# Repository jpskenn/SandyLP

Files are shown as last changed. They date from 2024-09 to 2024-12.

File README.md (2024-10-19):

# SandyLP（サンディ エルピー）

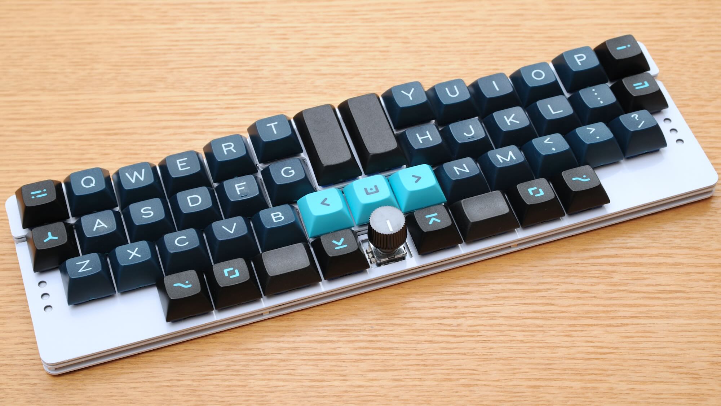
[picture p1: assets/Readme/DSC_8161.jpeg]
  

SandyLP is a 40% keyboard with symmetrical row staggered layout and key height optimization.

Layered PCB will make height differences for each key.
This covers the lack of optimization to physical key layout in two dimensions that only adjust x-y plane.

---

SandyLPは、スイッチの配置を立体的にして高さ方向への最適化を加えた、左右対称ロースタッガード配列の40%キーボードです。  

平面上のキーレイアウトだけでは最適化しきれない部分を、キーの位置に応じてスイッチを配置する高さを変えることで補っています。

前機種の[Sandy](https://github.com/jpskenn/Sandy)を元に、ロープロファイルスイッチへの対応と、レイアウトの調整をおこなっています。

名前の由来は、立体的、つまり3Dという意味を込めたSandyに、ロープロファイル版（＝ Low Profile version）を意味するLPを追加しました。

## 特徴

### 左右対称のキーレイアウト  

[Jones](https://github.com/jpskenn/Jones)と同様の、2行目と3行目にずれのない、左右対称なシンメトリカル ロースタッガードのレイアウトです。  
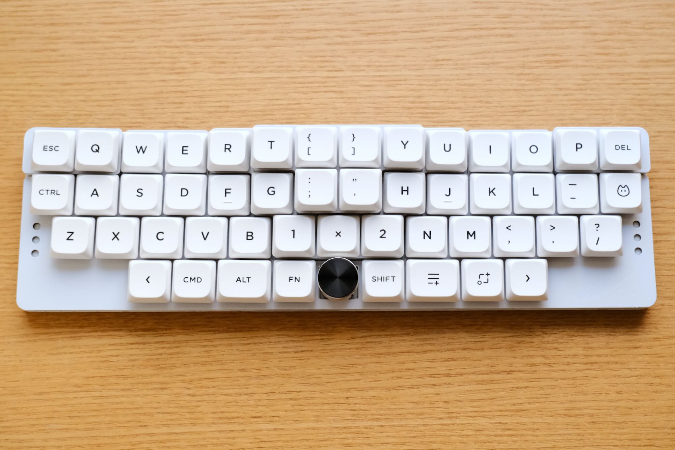
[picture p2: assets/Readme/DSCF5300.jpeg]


一般的なロースタッガードなレイアウトとの共通性を残しつつ、左右対称で打鍵しやすくなるよう、[SemiErgo Layout](https://github.com/mtei/SemiErgo_Layout)に準ずるキーマッピングで使用することを念頭に設計しています。  
Z行の左右端にシフトキーを用意していないので、スペースキーを「Space and Shift」として使うと便利です。

`T`と`Y`、`G`と`H`の間の2キーは実際のところそれほど使用することはありませんが、ここに2キー分の間隔があいてることで左右の手を広げることになり、肩を疲れにくくします。  
また、この間隔がゼロになると左右の親指が当たって動きを妨げてしまうため、あえて間隔をあけています。

このレイアウトは、市販の各種キーキャップセットのうち「Base Kit」と呼ばれる基本的なキットですべてを埋めることができます。また、104キーの英語キーキャップセットでも十分実用が可能です。
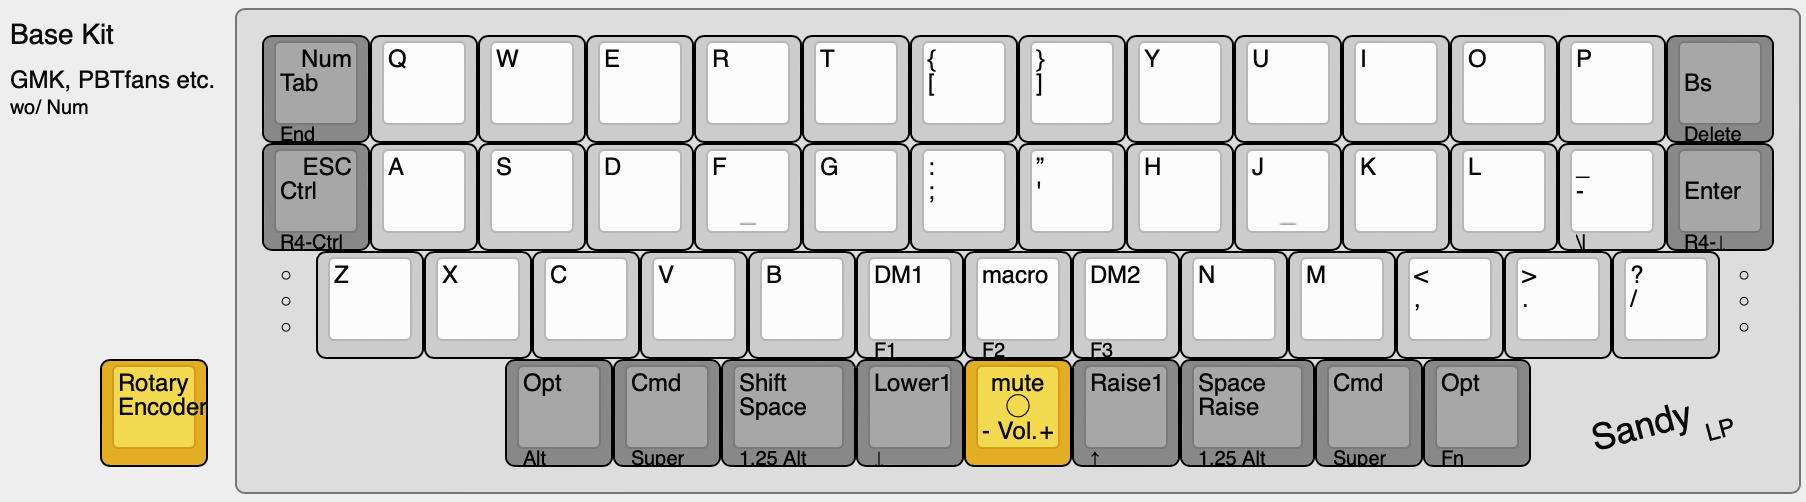
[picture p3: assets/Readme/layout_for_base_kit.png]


詳しくは、[Keyboard Layout Editor: SandyLP](https://www.keyboard-layout-editor.com/#/gists/29f5da09ffa69ab85efa4c68b556282b)を参照してください。

### キースイッチを立体的に配置  

前機種の[Sandy](https://github.com/jpskenn/Sandy)と同じく、キースイッチを3段階の高さで立体的に配置しています。  
平面上ではキーを配置できる範囲が限られるため、一部のキーはどうしても指が届きにくくなってしまいます。例えば、[Jones](https://github.com/jpskenn/Jones)では左右対称のレイアウトを採用することで右手小指の`P`や`Back Space`、`Enter`などは打鍵しやすくなりましたが、右手人差し指の`Y`は少し遠く感じられました。  
このような箇所について、キーの配置を高くすることで打鍵しやすさを向上させています。  

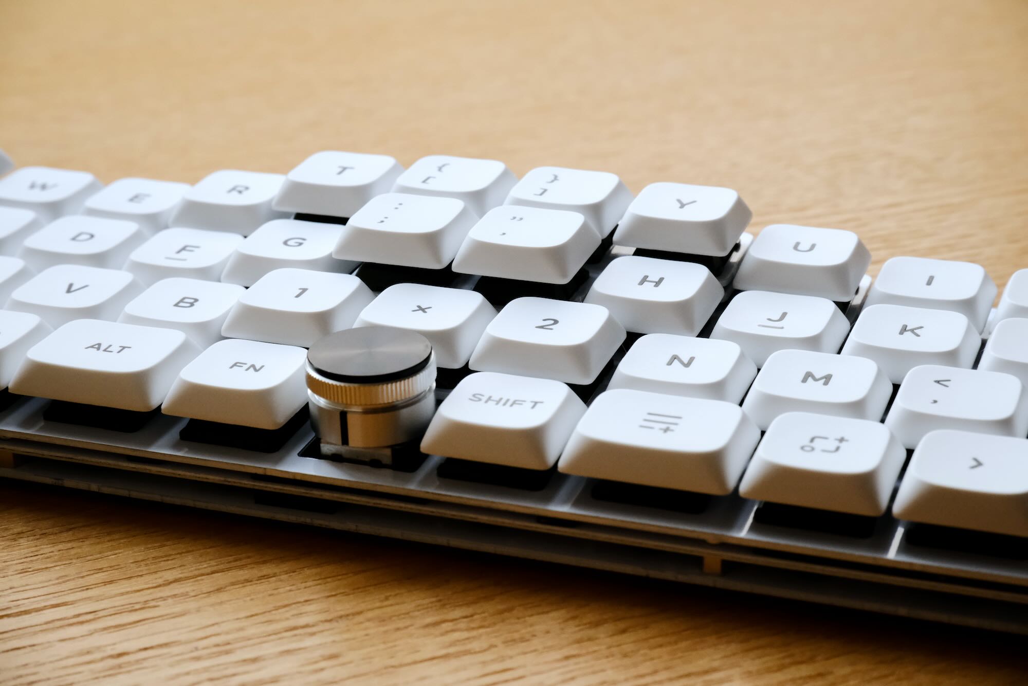
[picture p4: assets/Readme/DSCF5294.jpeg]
キースイッチの高さ（中央部分）

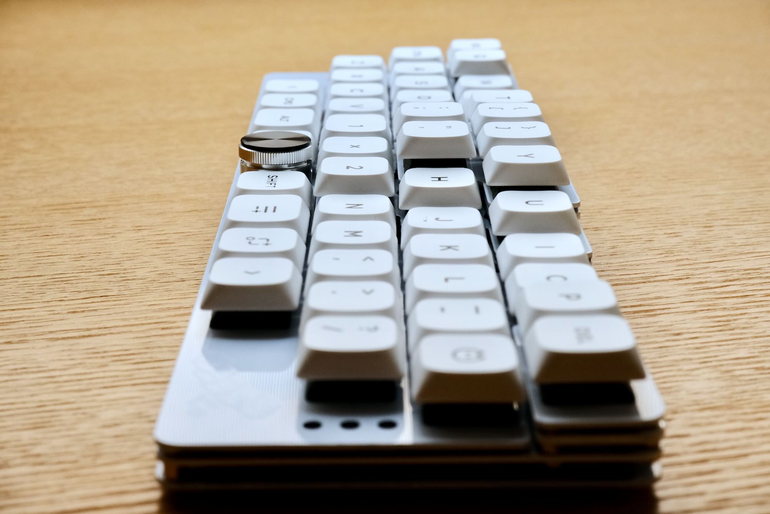
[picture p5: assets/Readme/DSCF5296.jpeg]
キースイッチの高さ（横から）


キーの高さはLow（基準高＝0mm）, Middle（3.6mm）, High（8.7mm）の3段階で、以下のように配置されます。  
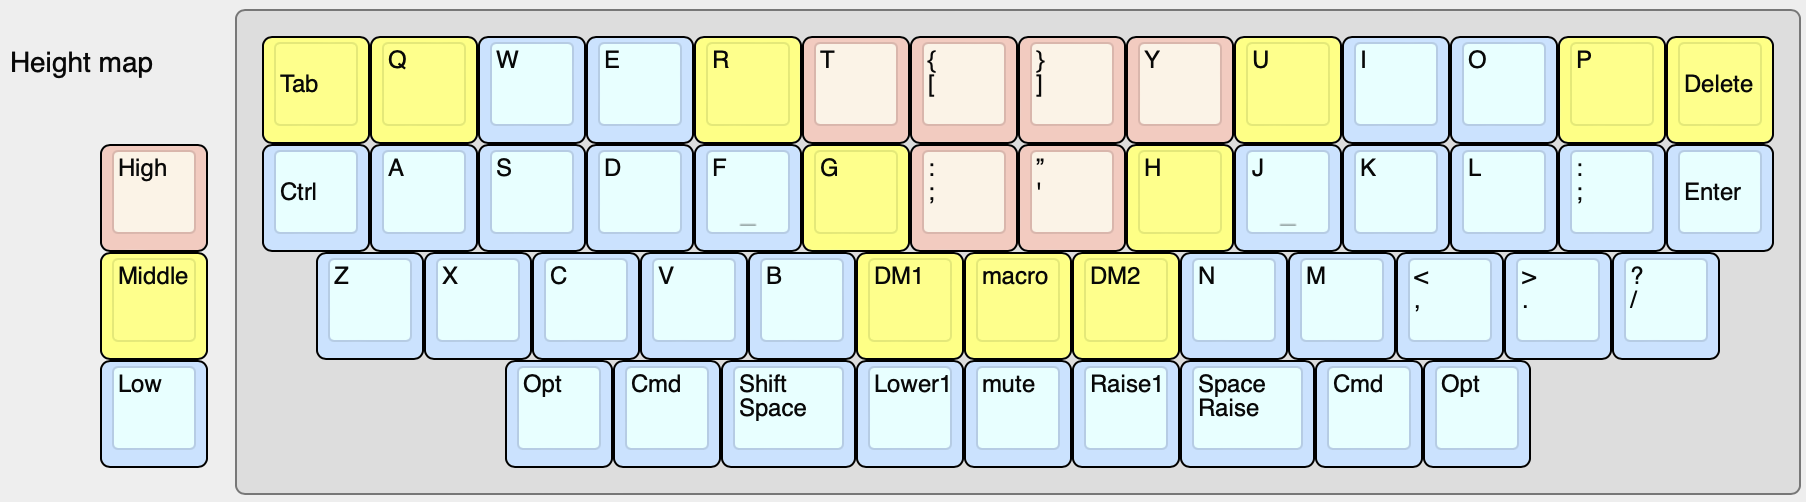
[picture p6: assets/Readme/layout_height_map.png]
キーの高さ


### キーボード自体が低い（薄い）  

ロープロファイルの`Choc V2`スイッチを採用することでキーボード自体が低くなりました。  
前機種のSandyからは7.2mm（※1）低くなり、パームレストを使わずとも、手首をあまり反らさないポジションで打鍵できます。

※1 ボトムプレートから1段目のスイッチ軸の天面までの高さを比較。なお、Sandyは理論上あと0.8mm低くすることが可能です。

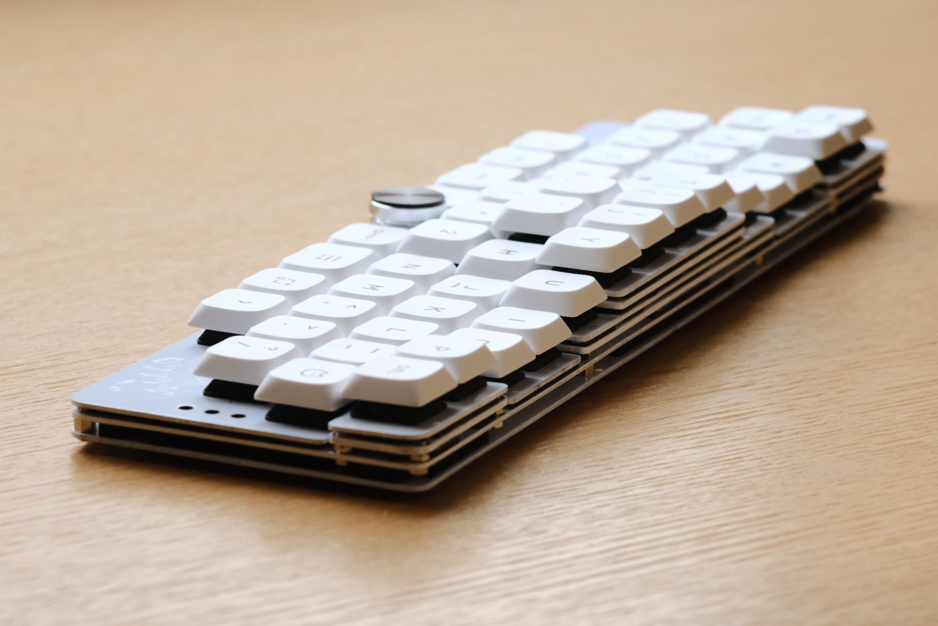
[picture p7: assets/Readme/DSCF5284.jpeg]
キースイッチの高さ


### RP2040を採用した構成により、多機能なファームウェアを使用可能

RP2040を採用した構成により、キーボード向けのファームウェアを格納するには十分すぎるほどのフラッシュ容量を得ることができました。  
エンコーダーやオーディオ、その他各種機能の同時有効化や、多数のレイヤーを使用するなど、多機能なファームウェアを使用可能です。

### Remap、Vialによるキー割り当ての変更  

初期書き込み済みのファームウェアは[Remap](https://remap-keys.app/)に対応しており、プログラミング等の知識がなくても、キーマッピングやロータリーエンコーダへの割り当てを、ブラウザ等を使って簡単に変更できます。  

また、Vial対応のファームウェアに書き換えて使用することもできます。

### オプション機能  

- ロータリーエンコーダ
- インジケータLED
- オーディオ

## ビルドガイド

- [SandyLP（DN0010）](/docs/BuildGuide_DN0010.md)（最新版）

## SNSタグ

[#SandyLP_kbd](https://twitter.com/search?q=%23SandyLP_kbd)

## ギャラリー

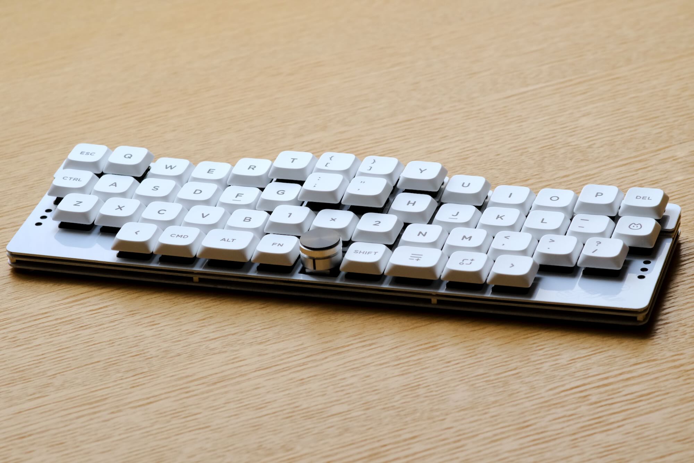
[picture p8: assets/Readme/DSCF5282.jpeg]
  
w/ NuPhy nSA BOW

SandyLP keyboard  
w/ Signature Plastics DSS Solarized Dark

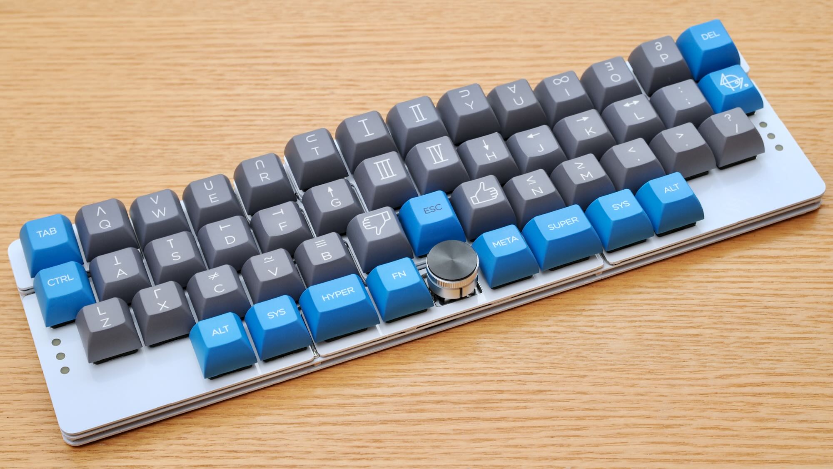
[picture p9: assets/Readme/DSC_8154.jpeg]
  
w/ Keyreative KAT Space Cadet, DN0011 Switch Plate

## 参考事例

- [TreK Lagoon](https://zenn.dev/digitarhythm/articles/a559b4b19fc959) by おおやけハジメ さん
- [Sparrow62](https://github.com/74th/sparrow62-buildguide/blob/master/sparrow62_v2.md) by 74th さん

## 開発経緯

以前開発した[Sandy](https://github.com/jpskenn/Sandy)を1年半ほど使い続け、日常使いの長期ロードテストとして十分な情報を得ることができました。  
その情報を元にSandyのアップデート版（Sandy DN0040）の開発をおこない、あとは基板製造の発注をするだけの段階となっていましたが、Sandyの課題のひとつとして挙げていた手首の負荷軽減、つまりキーボードを低くする変更を取り込まなかったことが様々な思いの中でほんのりと燻り続けていました。

ちょうどその頃、Choc V2スイッチのラインナップにたいへん素性の良い静音タイプが追加されました。そして、自分が普段好んで使っているMX用のキーキャップをそのスイッチと組み合わせて使えそうだという情報が得られたことから、ロープロファイルのスイッチを使用したSandyの派生版開発に踏み切りました。  

使用するスイッチの変更で、派生版の開発においてそこそこの量の設計変更が見込まれることから、ついでにキーレイアウトも変更することにしました。  
これまでに開発した`Jones`や`Sandy`では、頒布・販売することを念頭に想定するユーザーの最大公約数的なところへ歩み寄ったレイアウトにしていましたが、今回は自分の使用スタイルを最優先し、自分にとって不要な数字行や左右端のシフトキーなどを取り除いて、少し尖ったレイアウトに変更しました。

こうして、SandyLPが誕生することとなりました。

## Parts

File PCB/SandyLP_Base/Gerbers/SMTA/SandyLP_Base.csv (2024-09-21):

Reference | Value | Datasheet | Footprint | Qty | DNP | LCSC | LCSC-Reserve
C1,C2 | 10u | ~ | Capacitor_SMD:C_1206_3216Metric | 2 |  | C77090
C3,C4,C5,C6,C7,C8,C9,C10,C11,C12,C14,C15,C18,C19,C20,C21 | 100n | ~ | Capacitor_SMD:C_0402_1005Metric | 16 |  | C1525
C13,C16,C17 | 2.2uF | ~ | Capacitor_SMD:C_0402_1005Metric | 3 |  | C307418
D1,D2,D3,D4,D5,D6,D7,D8,D9,D10,D11,D12,D13,D14,D15,D16,D17,D18,D19,D20,D21,D22,D23,D24,D25,D26,D27,D28,D29,D30,D31,D32,D33,D34,D35 | D | ~ | locallib:D_SOD-123_Emphasized_Direction_Line_Reference_on_bottom | 35 |  | C81598
D99 | PRTR5V0U2X | https://assets.nexperia.com/documents/data-sheet/PRTR5V0U2X.pdf | Package_TO_SOT_SMD:SOT-143 | 1 |  | C78442
F1 | Fuse | ~ | Fuse:Fuse_0603_1608Metric | 1 |  | C187605
H_btm_1,H_btm_2,H_btm_3,H_btm_4,H_btm_5,H_btm_6,H_btm_7,H_btm_8,H_btm_9,H_btm_10,H_btm_11,H_mid_1,H_mid_2,H_mid_3,H_mid_4,H_mid_5,H_mid_6,H_mid_7,H_mid_8,H_mid_9,H_mid_10,H_mid_11,H_mid_12,H_mid_13,H_mid_14,H_mid_15,H_mid_16,H_mid_17,H_mid_18 | MountingHole | ~ | -- ミックスされた値 -- | 29
J1 | Conn_01x10_Pin | ~ | Connector_PinHeader_1.00mm:PinHeader_1x10_P1.00mm_Vertical | 1
J7 | USB_C_Receptacle_USB2.0 | https://www.usb.org/sites/default/files/documents/usb_type-c.zip | locallib:USB_C_Receptacle_HRO_TYPE-C-31-M-12 | 1 |  | C165948
J8 | Conn_01x03 | ~ | locallib:PinHeader_1x03_P2.54mm_Vertical_All_circle | 1
L1,L2,L3,L4,L5,L6 | SK6812MINI-E |  | locallib:YS-SK6812MINI-E_middle_hole_with_small_pad | 6
LOGO1 | Logo_Base | ~ | locallib:SandyLP_logo_w60 | 1
LS1,LS2 | Speaker | ~ | Buzzer_Beeper:Buzzer_Murata_PKMCS0909E | 2 |  |  | C910763
Q1 | BSS138 | https://www.onsemi.com/pub/Collateral/BSS138-D.PDF | Package_TO_SOT_SMD:SOT-23 | 1 |  | C78284
R1,R2 | 5.1k | ~ | Resistor_SMD:R_0402_1005Metric | 2 |  | C25905
R5,R8,R10,R11,R12,R13,R14 | 1k | ~ | Resistor_SMD:R_0402_1005Metric | 7 |  | C11702
R6,R7 | 27 | ~ | Resistor_SMD:R_0402_1005Metric | 2 |  | C25100
R9 | 10k | ~ | Resistor_SMD:R_0402_1005Metric | 1 |  | C25744
SD1 | Schottky diode | ~ | Diode_SMD:D_SOD-123 | 1 |  | C8598
STLED1 | LED_GREEN | ~ | LED_SMD:LED_0402_1005Metric | 1 |  | C130723
SW1 | BOOT | ~ | Button_Switch_SMD:SW_SPST_TL3342 | 1 |  |  | C2886897
SW2 | RESET | ~ | Button_Switch_SMD:SW_SPST_TL3342 | 1 |  |  | C2886897
SW_/1,SW_;1,SW_<1,SW_>1,SW_A1,SW_B1,SW_C1,SW_CTL1,SW_D1,SW_E1,SW_ENT1,SW_F1,SW_I1,SW_J1,SW_K1,SW_L1,SW_LALTu1,SW_LSPC1,SW_LWIN1,SW_M1,SW_N1,SW_O1,SW_R5CNT_L1,SW_R5CNT_R1,SW_RALT1,SW_RSPC1,SW_RWIN1,SW_S1,SW_V1,SW_W1,SW_X1,SW_Z1 | SW_Push | ~ | locallib:Kailh_socket_ChocV2 | 32
SW_R5CNT_C1 | RotaryEncoder_Switch | ~ | locallib:ChocV2_AND_RotaryEncoder_Alps_EC11K-Switch_Vertical_H20mm_NPTH_MP_minimal | 1
T_C0,T_C1,T_C2,T_C3,T_C4,T_C5,T_C6,T_R0,T_R1,T_R2,T_R3,T_R4,T_R5,T_R6,T_R7 | Conn_01x01 | ~ | locallib:TestPoint_THTPad_D2.0mm_Drill1.0mm | 15
U1 | NCP1117-3.3_SOT223 | http://www.onsemi.com/pub_link/Collateral/NCP1117-D.PDF | Package_TO_SOT_SMD:SOT-223-3_TabPin2 | 1 |  | C347222
U2 | RP2040 | https://datasheets.raspberrypi.com/rp2040/rp2040-datasheet.pdf | locallib:RP2040-QFN-56 | 1 |  | C2040
U3 | W25Q128JVPIQ | http://www.winbond.com/resource-files/w25q128jv_dtr%20revc%2003272018%20plus.pdf | Package_SON:WSON-8-1EP_6x5mm_P1.27mm_EP3.4x4.3mm | 1 |  | C190862
Y1 | 12MHz | ~ | Crystal:Resonator_SMD_Murata_CSTxExxV-3Pin_3.0x1.1mm | 1 |  | C341520

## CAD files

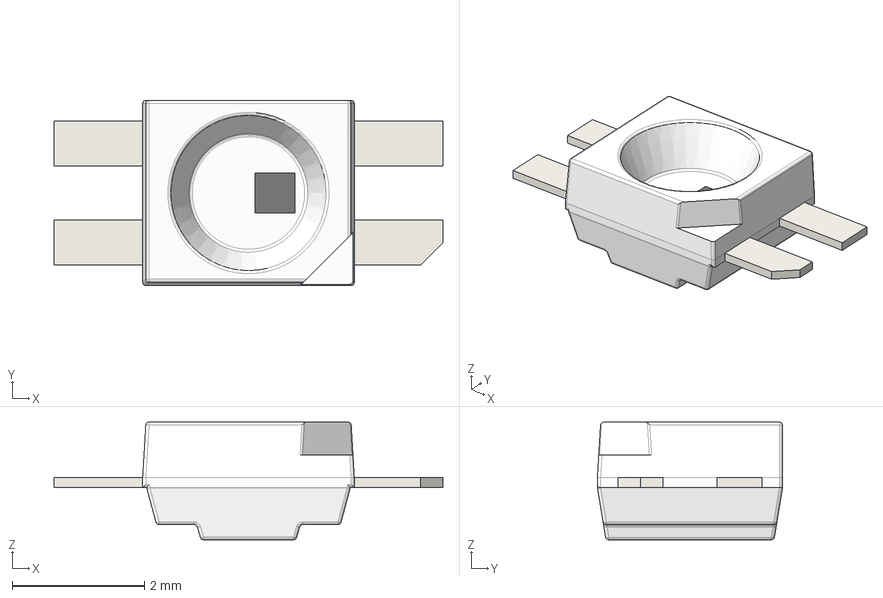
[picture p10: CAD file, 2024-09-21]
PCB/SandyLP_Base/lib_LED/LED_SK6812MINI-E.step
5.88 x 2.80 x 1.78 mm

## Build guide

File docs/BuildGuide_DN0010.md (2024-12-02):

# SandyLP（DN0010）ビルドガイド

このドキュメントは、SandyLP（DN0010）を組み立てるためのビルドガイドです。

開発番号の`DN0010`は、各基板のうら側に記載されています。  
（Mid左右用スイッチプレートには記載がありません。）
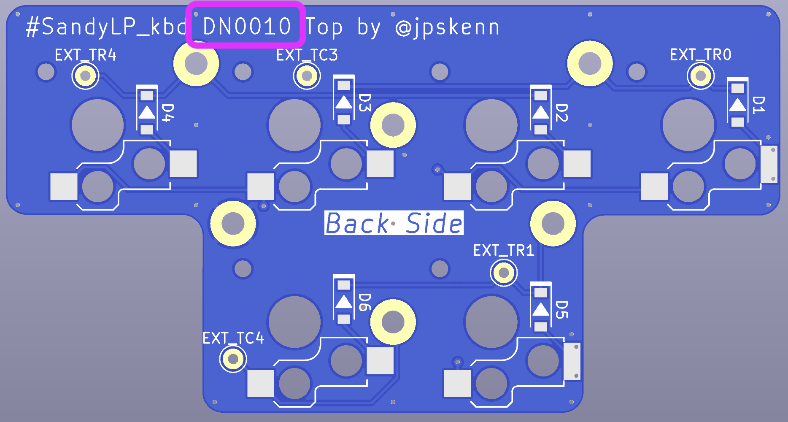
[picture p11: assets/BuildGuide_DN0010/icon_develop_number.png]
開発ナンバー


SandyLPのコンセプトや特徴、ビルド例などについては、こちらの[README](/README.md)をご覧ください。

ビルドガイド全体に目を通して作業手順を把握しておくとミスの防止につながりますので、ぜひ、一度お読みになってから組み立て作業を始めてください。

## 目次

<!-- @import "[TOC]" {cmd="toc" depthFrom=1 depthTo=3 orderedList=false} -->

<!-- code_chunk_output -->

- [SandyLP（DN0010）ビルドガイド](#sandylpdn0010ビルドガイド)
  - [目次](#目次)
  - [注意事項](#注意事項)
  - [部品リスト](#部品リスト)
    - [キット内容](#キット内容)
    - [別途用意が必要な部品](#別途用意が必要な部品)
    - [オプション部品](#オプション部品)
  - [組み立てに使用する工具](#組み立てに使用する工具)
  - [組み立て手順](#組み立て手順)
    - [組み立て前の確認](#組み立て前の確認)
    - [【こだわり作業】基板とスイッチプレート側面をマジックで塗る](#こだわり作業基板とスイッチプレート側面をマジックで塗る)
    - [部品のはんだ付け](#部品のはんだ付け)
    - [基板へのネジ止めとゴムシート貼り](#基板へのネジ止めとゴムシート貼り)
    - [スイッチプレートへのゴムシート貼り](#スイッチプレートへのゴムシート貼り)
    - [基板とスイッチプレートをひとつに組み合わせて、スイッチを取り付ける](#基板とスイッチプレートをひとつに組み合わせて-スイッチを取り付ける)
    - [動作確認する](#動作確認する)
    - [ボトムプレートを取り付ける](#ボトムプレートを取り付ける)
    - [キーキャップを取り付ける](#キーキャップを取り付ける)
  - [ユーザーズマニュアル・カスタマイズガイド](#ユーザーズマニュアルカスタマイズガイド)
    - [初期ファームウェアの機能と設定値](#初期ファームウェアの機能と設定値)
    - [SandyLP関連ファイル](#sandylp関連ファイル)
    - [ファームウェアを書き換える](#ファームウェアを書き換える)
    - [EEPROMを消去して初期状態に戻す](#eepromを消去して初期状態に戻す)
    - [電源LEDを点灯しないようにする](#電源ledを点灯しないようにする)
    - [キーキャップの選び方](#キーキャップの選び方)
  - [サービスマニュアル](#サービスマニュアル)
    - [パーツリスト](#パーツリスト)
    - [基板セットアップ](#基板セットアップ)

<!-- /code_chunk_output -->

## 注意事項

開発ナンバー`DN0010`と`DN0011`はSandyLPの試作版であり、組み立てやすくする工夫や細部の調整が施されていません。

半田付けするのが難しい箇所があったりするため、自作キーボードや電子工作についてある程度わかっている方や、多少のことは自分でなんとかできる方以外は手を出さないようにしてください。

## 部品リスト

このキットを組み立てて完成させるためには、[キット内容](#キット内容)に加え、[別途用意が必要な部品](#別途用意が必要な部品)が必要です。  

[オプション部品](#オプション部品)は用意しなくてもかまいません。使いたい機能に応じて用意してください。  

### キット内容

このキットに同梱されている部品等の内容です。  

| 部品名 | 個数 | 備考 |
| :-- | :--: | :-- |
| ご案内リーフレット | 1 | |
| 基板Base | 1 | この基板のみ、多数の部品を取り付け済み。 |
| 基板Mid中央 | 1 | |
| 基板Mid左右 | 2 | 同一形状の2枚のうち、ひとつをおもて側、もうひとつをうら側にして使用。 |
| 基板Top | 1 ||
| Base用スイッチプレート | 1 | 両面使えるリバーシブル仕様。好みのデザインの面をおもて側にして使用。 |
| Mid中央用スイッチプレート | 1 ||
| Mid左右用スイッチプレート | 2 | 同一形状の2枚のうち、ひとつをおもて側、もうひとつをうら側にして使用。 |
| Top用スイッチプレート | 1 | |
| ボトムプレート | 1 ||
| 短いスペーサー<br>両メネジ M2 3mm | 11 | [ヒロスギ ASB-2003E](https://hirosugi.co.jp/products/B/ASB-E.html#bx3) |
| 長いスペーサー<br>両メネジ M2 3.5mm | 6 |  [ヒロスギ ASB-2003.5E](https://hirosugi.co.jp/products/B/ASB-E.html#bx3) |
| ナット<br>M2 2種 高さ1.6mm | 35 | 予備1個含む。[ウィルコ FNT-02N-2](https://wilco.jp/products/F/FNT-N-2.html) |
| ワッシャー<br>M2 内径2.3mm 外径4.3mm 厚さ0.4mm| 19 | 予備1個含む。[ウィルコ FW-0204-04N](https://wilco.jp/products/F/FW-N.html#page3) |
| 短いネジ（2mm）<br>M2 2mm | 11 | [十字穴付なべ小ねじ](https://jp.misumi-ec.com/vona2/detail/110302280810/?ProductCode=BKJ2-2) |
| 短いネジ（3mm）<br>M2 3mm | 22 | 予備1個含む。[ウィルコ F-0230N-02](https://wilco.jp/products/F/F-N-02.html#page3) |
| 長いねじネジ<br>M2 6mm | 19 | 予備1個含む。[ウィルコ F-0260N-02](https://wilco.jp/products/F/F-N-02.html#page3) |
| ゴム足（大） | 2 | [光 HIKARI KKU-190](https://www.yodobashi.com/product/100000001001980663/) |
| ゴム足（小） | 5 | [CS-102](https://www.3mcompany.jp/3M/ja_JP/p/d/v000453068/) |
| ダイオード<br>1N4148W SOD123 | 20 | 予備3個含む。<br>[高速スイッチング・ダイオード 1N4148W](https://akizukidenshi.com/catalog/g/g107084/) |
| LED<br>SK6812MINI-E | 6 | [マイコン内蔵ＲＧＢＬＥＤ　ＳＫ６８１２ＭＩＮＩ－Ｅ](https://akizukidenshi.com/catalog/g/gI-15478/) |
| Chocスイッチ用ソケット | 50 | 最下行中央にロータリーエンコーダを取り付けない場合は49個。<br>[Kailh Switch Socket（Kailh Choc ロープロファイル用）](https://shop.yushakobo.jp/products/a01ps?variant=37665172553889) |
| 太くて薄いゴムシート<br>T=1mm 10mm * 500mm | 1+1/3 | [低弾性ゴムシート－ハネナイトＲ－](https://jp.misumi-ec.com/vona2/detail/110300277050/?ProductCode=UNLEA1-10) |
| 小さな薄いゴムシート<br>T=1.5mm 50mm * 10mm | 1 | [イノアック L32-1.550-MT マイクロセルウレタンロールPORON 黒 1.5×50mm×1M巻](https://www.yodobashi.com/product/100000001004002516/) |
| 細くて薄いゴムシート<br>T=2mm 5mm * 500mm | 1 | [低弾性ゴムシート－ハネナイトＲ－](https://jp.misumi-ec.com/vona2/detail/110300277050/?ProductCode=UNSEA2-5)
| 細くて分厚いゴムシート<br>T=3mm 5mm * 500mm | 1 | [低弾性ゴムシート－ハネナイトＲ－](https://jp.misumi-ec.com/vona2/detail/110300277050/?ProductCode=UNSEA3-5) |
| プラ板（乳白色）<br>T=0.3mm 約15m * 約20mm | 1 | LEDディフューザーとして使用。<br>[プラバン 0.3mm厚 B4サイズ （5枚入）](https://www.tamiya.com/japan/products/70122/index.html) |

※出荷時期によって、機能的に同等なものへ変更することがあります。

基板  
左上から時計回りに、基板Top、基板Mid中央、基板Mid左右（2枚）、基板Base。  
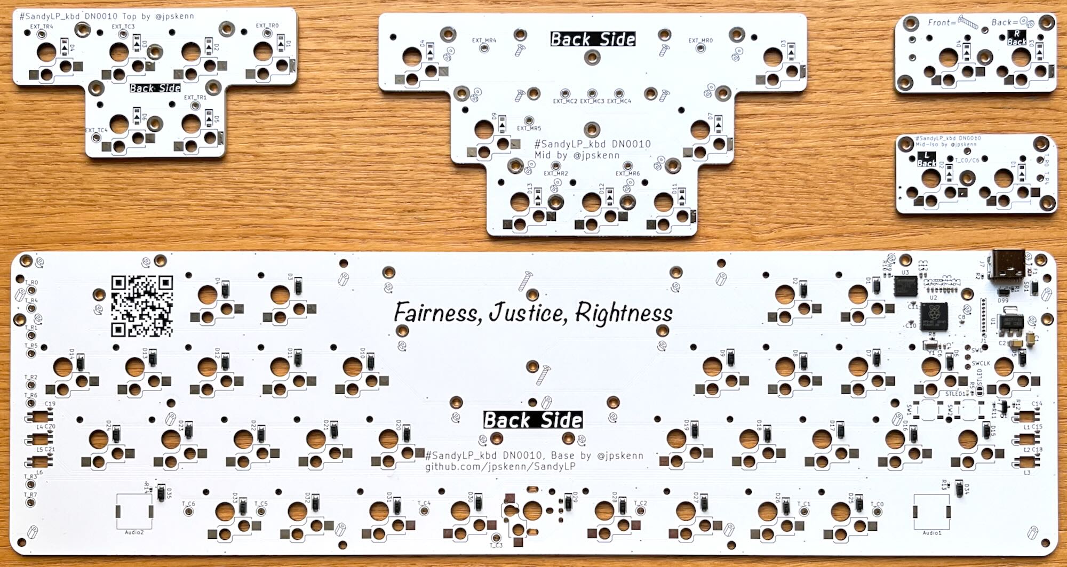
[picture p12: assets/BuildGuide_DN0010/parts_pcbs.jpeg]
基板
  

プレート類  
左上から時計回りに、Top用スイッチプレート、Mid中央用スイッチプレート、Mid左右用スイッチプレート（2枚）、Base用スイッチプレート、ボトムプレート。  
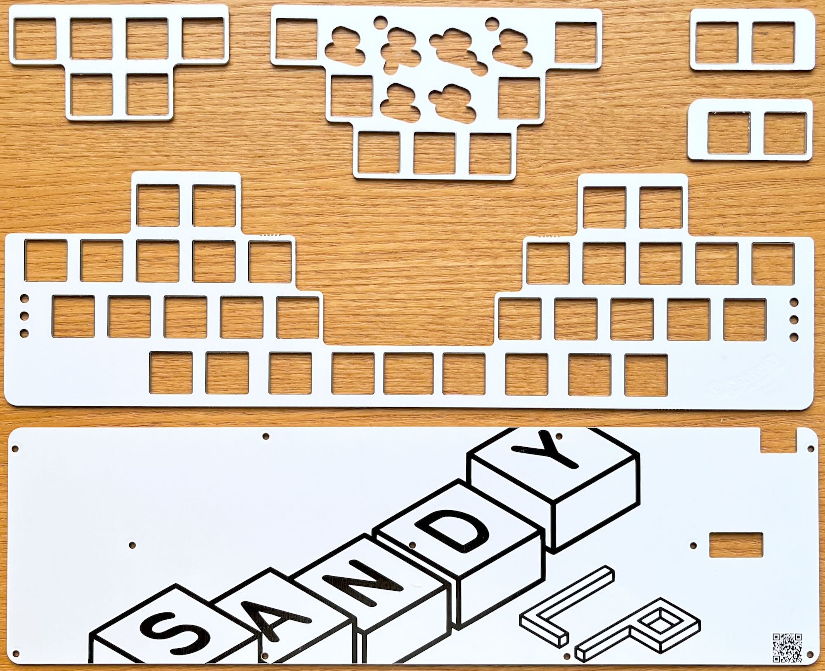
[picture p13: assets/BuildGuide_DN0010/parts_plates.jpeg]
プレート類
  

その他部品  
その他部品  
〓ネジとかは乗せなくても良いけど、ゴムシートは見分けがつきにくいので、写真を載せる。

### 別途用意が必要な部品

完成させるには、キット内容とは別に、以下の部品を用意する必要があります。

| 部品名 | 個数 | 備考 |
| :-- | :--: | :-- |
| Choc V2スイッチ | 50 | ロータリーエンコーダを取り付ける場合は49個。<br>Choc V1スイッチは、固定ピンがないもの、または固定ピンを取り外したものであれば取り付け可能。<br>ピン折れなどの保険用に5個くらい多めに買っておくとよい。 |
| キーキャップ<br>Choc V2スイッチ用 | 必要数 | GMKやePBT等のいわゆるBase Kitを使用すると、良い具合に仕上げることが可能。<br>一部のMXスイッチ用のキーキャップは、組み合わせによってはスイッチプレートやスイッチに干渉する場合あり。<br>詳しくは[キーキャップの選び方](#キーキャップの選び方)を参照。 |
| USBケーブル （Type-C） | 1 | Base基板に取り付けられているコネクタはType-Cです。 |

### オプション部品

オプション部品は無くてもかまいません。  
使いたい機能に応じて用意します。

| 部品名 | 個数 | 備考 |
| :-- | :--: | :-- |
| ロータリーエンコーダ<br>ALPS EC11, EC12同等品 | 1 | ロータリーエンコーダを使用する場合。<br>プッシュスイッチ付きにも対応。 |
| ロータリーエンコーダ用ノブ（つまみ） | 1 | ロータリーエンコーダを使用する場合。 |
| スピーカー<br>Murata PKMCS0909E4000-R1 | 1 | [PKMCS0909E4000-R1](https://www.digikey.jp/ja/products/detail/murata-electronics/PKMCS0909E4000-R1/4878400) |
| 両面テープ | 適量 | LEDディフューザーを取り付ける場合。 |

## 組み立てに使用する工具

こちらの[工具セット](https://shop.yushakobo.jp/products/a9900to)などを参考に工具を用意します。

- 必要な工具

  - M2ネジに対応する、先の細いプラスドライバー（+0）

  - はんだ付け関連用品

    はんだ、はんだごて（温度調整機能つきを推奨）、こて台、ピンセットなど。  
    小さな部品のはんだ付けや、ちょっとした修正、取り外しなどの作業がしやすくなるので、フラックスやハンダ吸い取り線もあると良いでしょう。

  - はさみ または カッター
    ゴムシートの切断に使用。

- あると便利な工具

  - マジックペン

    基板の側面を塗ると、完成時の質感が上がります。  
    暗めの色を塗る場合は[プロッキー](https://www.mpuni.co.jp/products/felt_tip_pens/water_based/sign_pen/prockey.html)を、明るめの色を塗る場合は不透明顔料インクの[ポスカ](https://www.mpuni.co.jp/products/felt_tip_pens/water_based/posca/standard.html)を使うなど、お好みで。

  - M2ナット対応のレンチ，ナットドライバー

    ナットを締める箇所が多いので、あると作業が格段に楽になります。  
    [タミヤ SP.38 工具セット](https://www.tamiya.com/japan/products/50038/index.html)の十字レンチが安くておすすめ。

  - テスター  
    はんだ付けの確認作業や、何か不具合があった場合の原因調査で活躍します。

## 組み立て手順

手順に沿って、順番に組み立てます。

- 【こだわり作業】の手順は、完成時の質感を重視した内容であり、不要であれば作業をとばしてもかまいせん。

- 【該当者のみ】の手順は、条件に該当する場合のみ作業します。

- おもて側とうら側を間違えないよう、基板うら側の「Back Side」の表記を確認しながら作業を進めます。

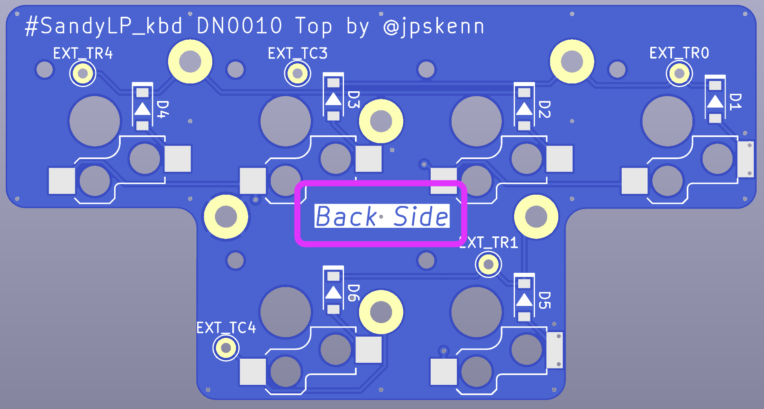
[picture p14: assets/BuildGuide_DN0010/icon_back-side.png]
Back Sideの表記
  

### 組み立て前の確認

出荷前に基本的な動作確認を実施済みですが、輸送時の破損なども考えられるため、組み立てを始める前に動作確認をおこないます。  
確認結果に問題がある場合は、リーフレットに記載の連絡先へ相談してください。

#### 基板BaseがPCやMacで認識されるかを確認する

1. `基板Base`を、うら側を上にして安定した場所へ置く。

1. `基板Base`のUSBコネクタへケーブルを差し込み、PCやMacに接続する。

1. 電源LED`STLED1`が緑に点灯することを確認する。

1. PCやMacで、キーボードとして認識されていることを確認する。  
    確認例：
    - Windows 11  
    設定 → Bluetoothとデバイス → デバイス → 入力  
    「sandy_lp」が表示されていること。

    - Mac  
    システムレポート → USB  
    「sandy_lp」が表示されていること。

#### 基板Baseの反応を確認する

1. [Remap（https://remap-keys.app/）](https://remap-keys.app/)を、対応するブラウザ（ChromeやEdgeなど）で開く。

1. `CUSTOMIZE YOUR KEYBOARD`ボタンを押す。

1. `+ KEYBOARD`を押す。

1. ポップアップ画面で`sandy_lp`を選択して、`接続`を押す。  
    次の画面で`Please import your sandy_lp definition file(.json).`というメッセージが表示された場合
    1. 別途、[SandyLPのVIA用jsonファイル（sandylp_via.json）](https://github.com/jpskenn/SandyLP/blob/main/VIA/sandylp_via.json)をダウンロードしておく。
    1. Remapの画面で`IMPORT(.JSON)`を押し、ダウンロードしておいた`sandylp_via.json`を選択して開く。

1. 画面にキーボードのレイアウトが表示されるまでしばらく待つ。

    30秒待っても表示されないときは、ブラウザをリロードしてやり直します。

1. キーボードのレイアウトの右側の一番下にある`…`をクリックして、表示されたメニューから`Test Matrix Mode`を選択する。

1. キースイッチの反応を確認する。

    `基板Base`うら側のスイッチソケット取り付け用パッド（銀色の四角い端子部分）をピンセットなどでショートさせ、ブラウザ画面上の対応するキーの色が変わることを確認します。

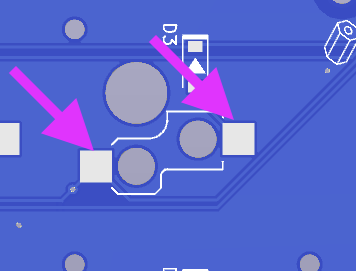
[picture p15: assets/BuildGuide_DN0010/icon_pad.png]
スイッチ取り付け用パッド
    

    すべてのパッドで実施した後、以下のように色が変われば正常です。  
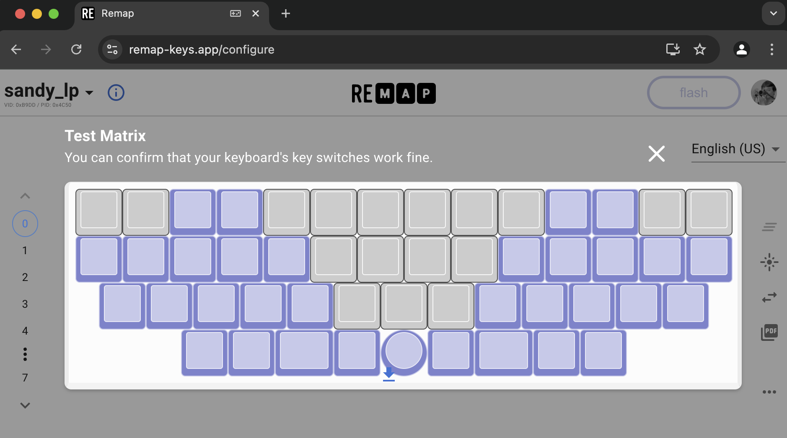
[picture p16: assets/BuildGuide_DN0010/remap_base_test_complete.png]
基板Base確認結果
    

### 【こだわり作業】基板とスイッチプレート側面をマジックで塗る

完成時の質感を高めるため、すべての基板とスイッチプレート、ボトムプレートの側面をマジックで塗ります。

💡ヒント：組み立て後は、スイッチを取り外したりネジを外して分解したりしないと塗れなくなる箇所があります。後からやるのは大変なので、この段階でやってしまった方が楽です。

### 部品のはんだ付け

#### 基板Topへのはんだ付け

1. `基板Top`を、うら側の「Back Side」と書かれた面が見えるように置く。

1. `ダイオード`を取り付ける。（6個）

    基板のダイオード用パッド2個のうち、片方のパッドに予備はんだ（はんだを少しだけつけておく）します。  
    基板に描かれた枠のうち、短辺が閉じている方向（▲マークが示す先の少し太い線がある方向）にダイオードの印を合わせ、予備はんだしたところへ、ダイオードの端子をはんだ付けします。  
    最後に、もう一方の端子をはんだ付けします。

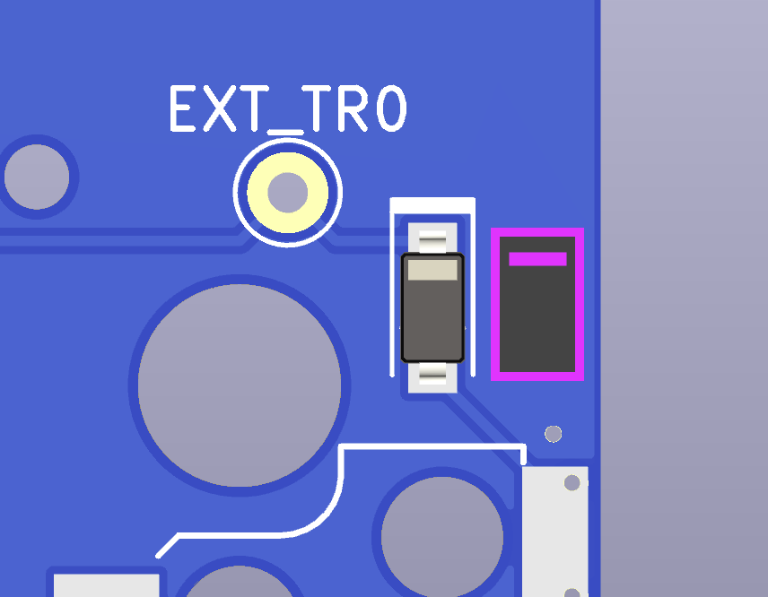
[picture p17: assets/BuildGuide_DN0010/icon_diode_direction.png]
    
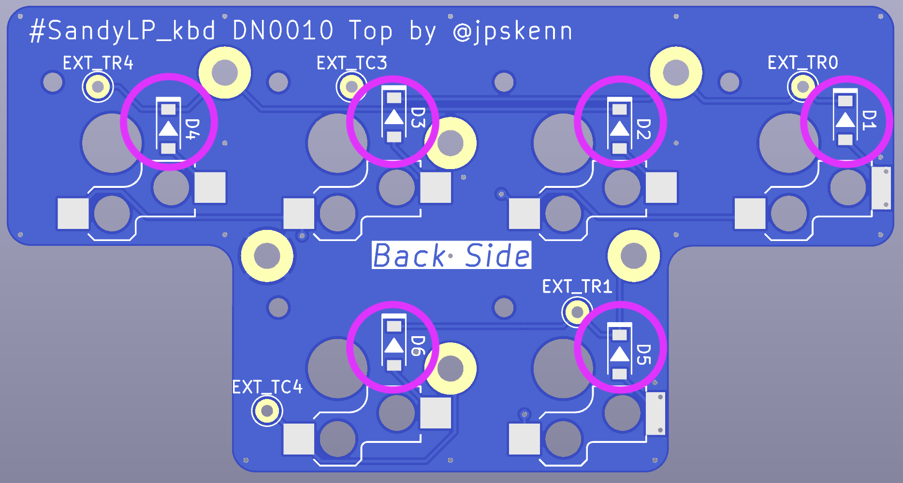
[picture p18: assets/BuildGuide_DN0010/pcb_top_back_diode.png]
    

1. `Chocスイッチ用ソケット`を取り付ける。（6個）

    基板に描かれた枠に合わせてソケットを置きます。  

    💡ヒント：Chocスイッチ用ソケットは、取り付ける方向が決まっています。参考：[Kailh Choc ソケットの方向について](https://scrapbox.io/self-made-kbds-ja/Kailh_Choc_ソケットの方向について)

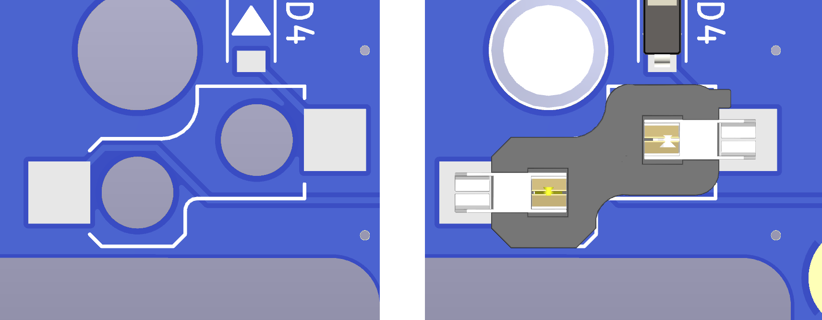
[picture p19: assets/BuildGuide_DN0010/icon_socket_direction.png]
    

    はんだごての温度を270度程度にセットして、はんだ付けします。  

    ソケットが基板から浮かないように注意し、基板にぴったりと接するように取り付けます。

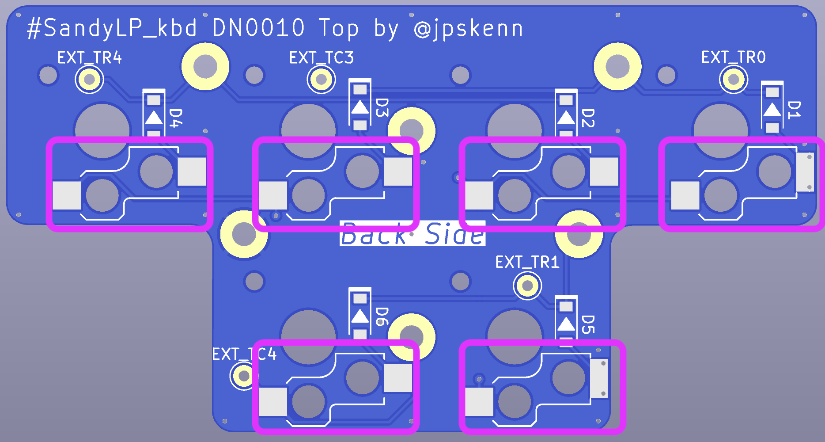
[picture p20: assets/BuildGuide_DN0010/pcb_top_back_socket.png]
    

#### 基板Mid中央へのはんだ付け

1. `基板Mid中央`を、うら側の「Back Side」と書かれた面が見えるように置く。

1. `ダイオード`を取り付ける。（7個）

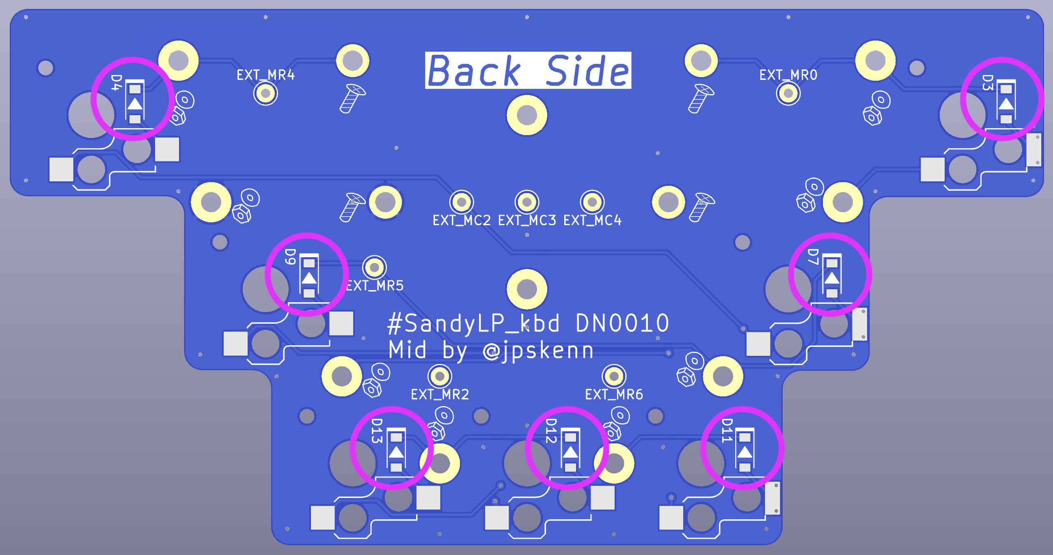
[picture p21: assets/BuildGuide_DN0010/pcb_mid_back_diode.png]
    

1. `Chocスイッチ用ソケット`を取り付ける。（7個）

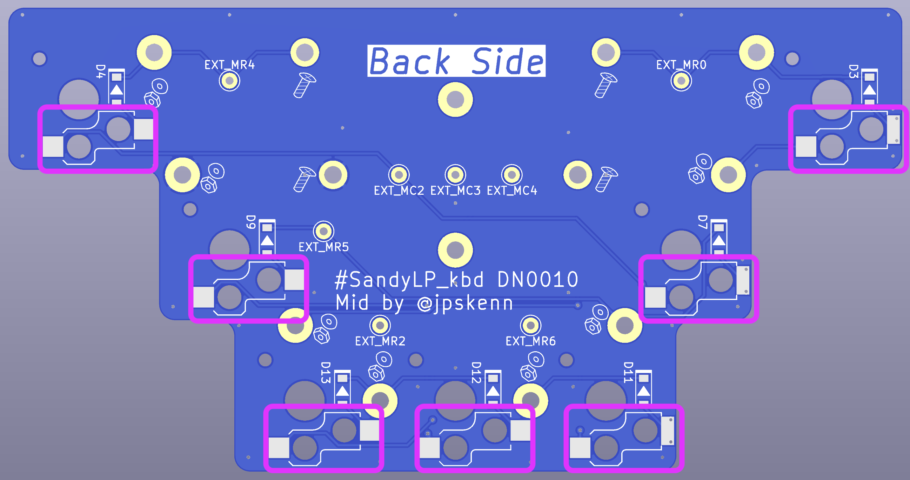
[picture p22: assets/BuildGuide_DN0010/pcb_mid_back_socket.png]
    

#### 基板Mid左右へのはんだ付け

1. `基板Mid左右`2枚のうち、ひとつを「L Back」と書かれた面が見えるように置き、もうひとつを「R Back」と書かれた面が見えるように置く。

1. `ダイオード`を取り付ける。（左右それぞれ2個、計4個）

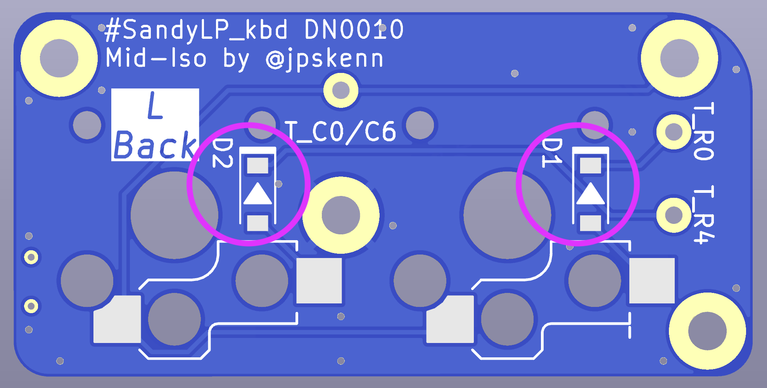
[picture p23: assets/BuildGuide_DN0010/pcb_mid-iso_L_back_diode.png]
    

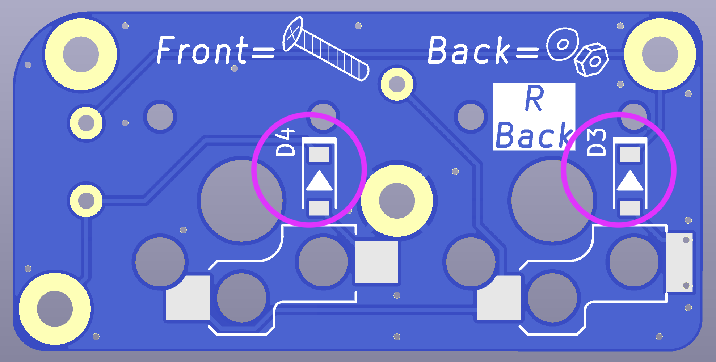
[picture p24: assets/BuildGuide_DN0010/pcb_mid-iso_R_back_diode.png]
    

1. `Chocスイッチ用ソケット`を取り付ける。（左右それぞれ2個、計4個）

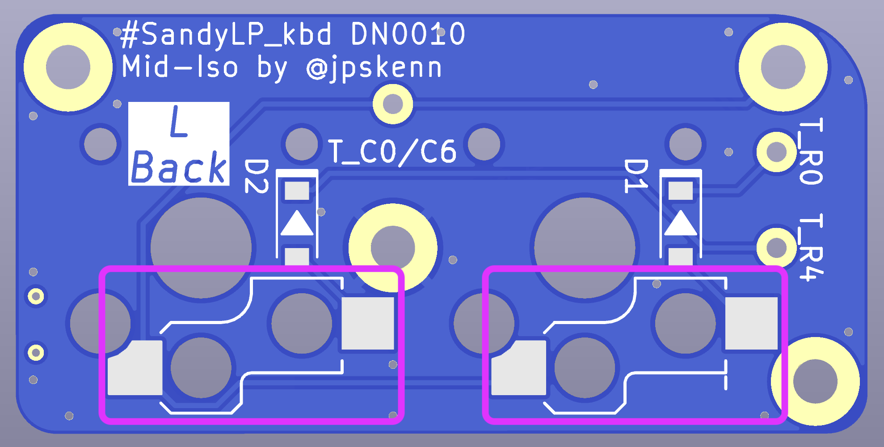
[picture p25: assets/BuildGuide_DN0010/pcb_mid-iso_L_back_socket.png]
    

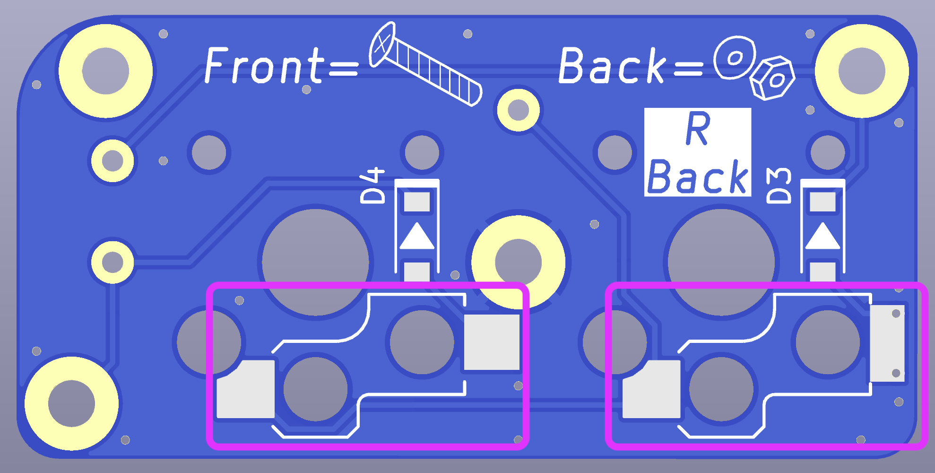
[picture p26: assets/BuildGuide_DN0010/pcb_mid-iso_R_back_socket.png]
    

#### 基板Baseへのはんだ付け

1. `基板Base`を、うら側の「Back Side」と書かれた面が見えるように置く。

1. うら側から、`Chocスイッチ用ソケット`を取り付ける。（33個。ロータリーエンコーダを取り付ける場合は32個）

    ロータリーエンコーダを取り付ける場合は、最下行中央のソケットは取り付けません。

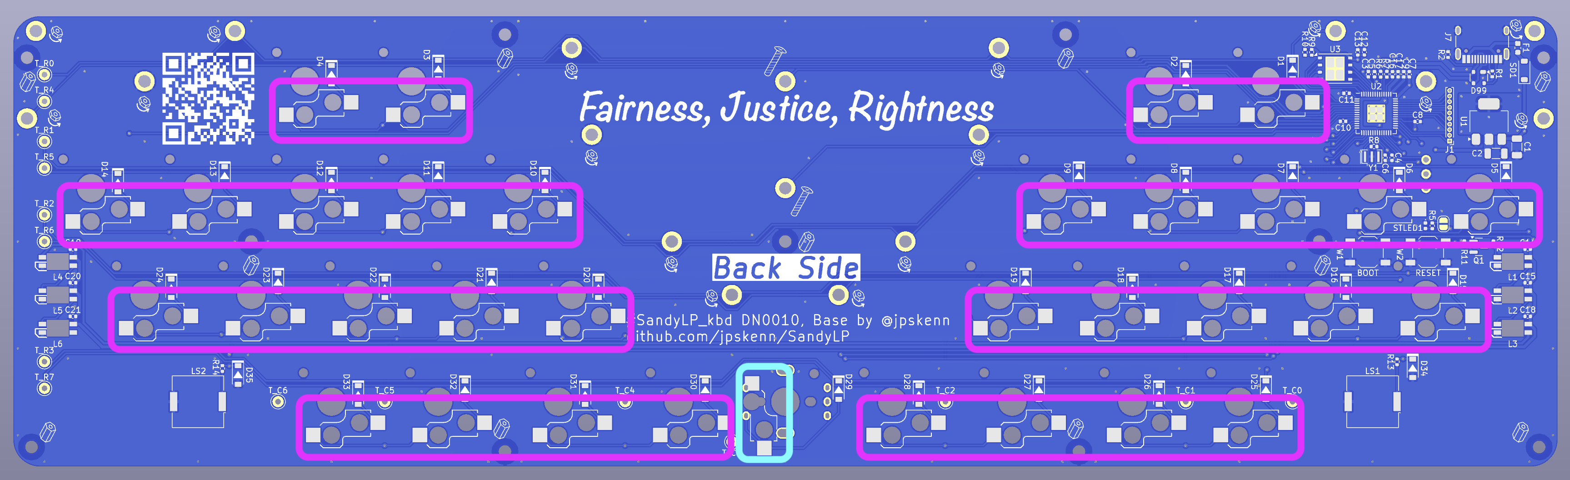
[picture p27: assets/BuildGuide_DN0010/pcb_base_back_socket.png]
    

1. 【該当者のみ】うら側から`LED`を取り付ける。（左右に3個ずつ。計6個）

    条件：インジケータLEDを使用する場合

    取り付け場所：うら側 `L1` から `L6`

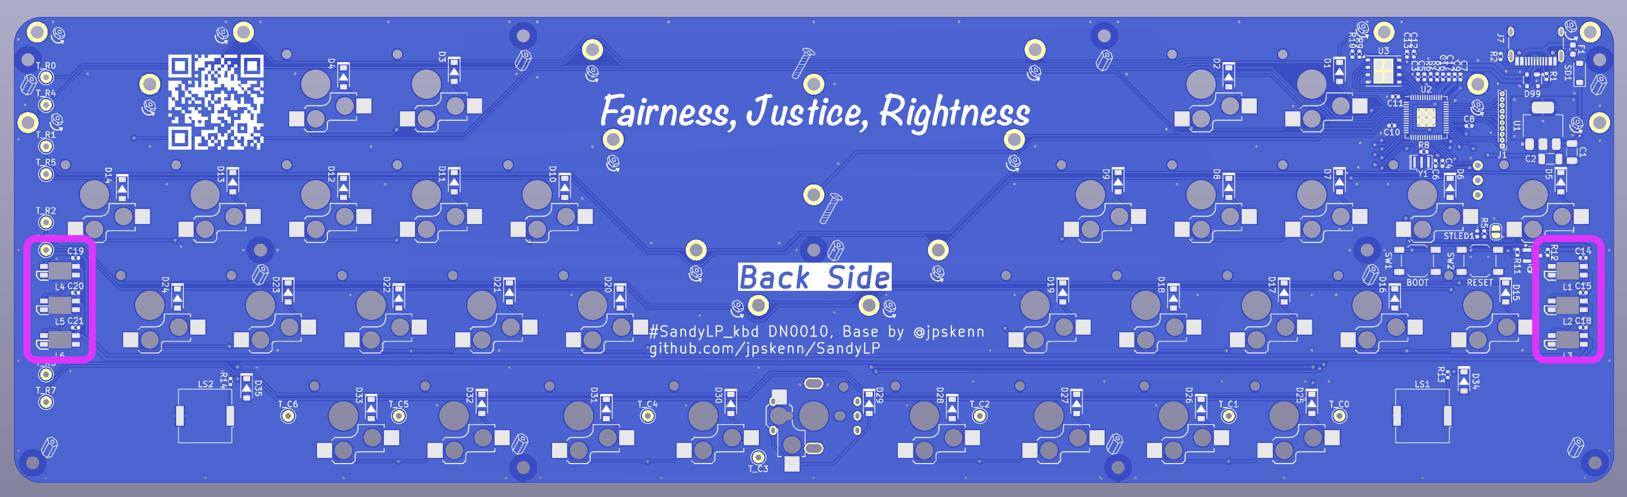
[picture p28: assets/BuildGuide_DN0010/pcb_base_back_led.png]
    

    LED取り付け用パッド（1個のLEDに4個のパッド）のひとつに、予備はんだしておきます。  
    基板に描かれた印にLEDの端子の切り欠き部分を合わせ、LED発光部が基板おもて側になるように置きます。  

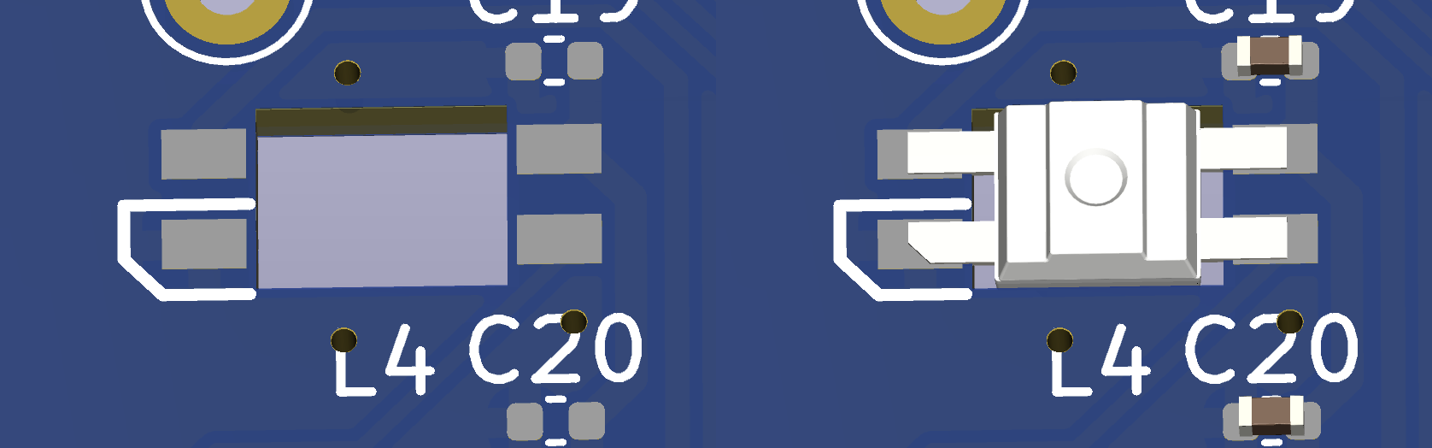
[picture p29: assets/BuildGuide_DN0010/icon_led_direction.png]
    

    予備はんだした箇所を、220度程度の温度ではんだ付けします。  
    （はんだが溶けにくい場合は、270度程度まで温度を上げ、短時間で作業します。）

    残りのパッドをはんだ付けします。

    6個すべてのLEDを取り付けたら、USBケーブルでPCやMacに接続し、LEDがすべて白色に点灯することを確認します。  
    （ケーブル接続時に一瞬だけ赤色に点灯する場合がありますが、正常な動作です。）

1. 【該当者のみ】うら側から`スピーカー`を取り付ける。

    条件：スピーカーを使用する場合

    取り付け場所：うら側 `LS1`（`LS2`は実験用のため、取り付けしません。）

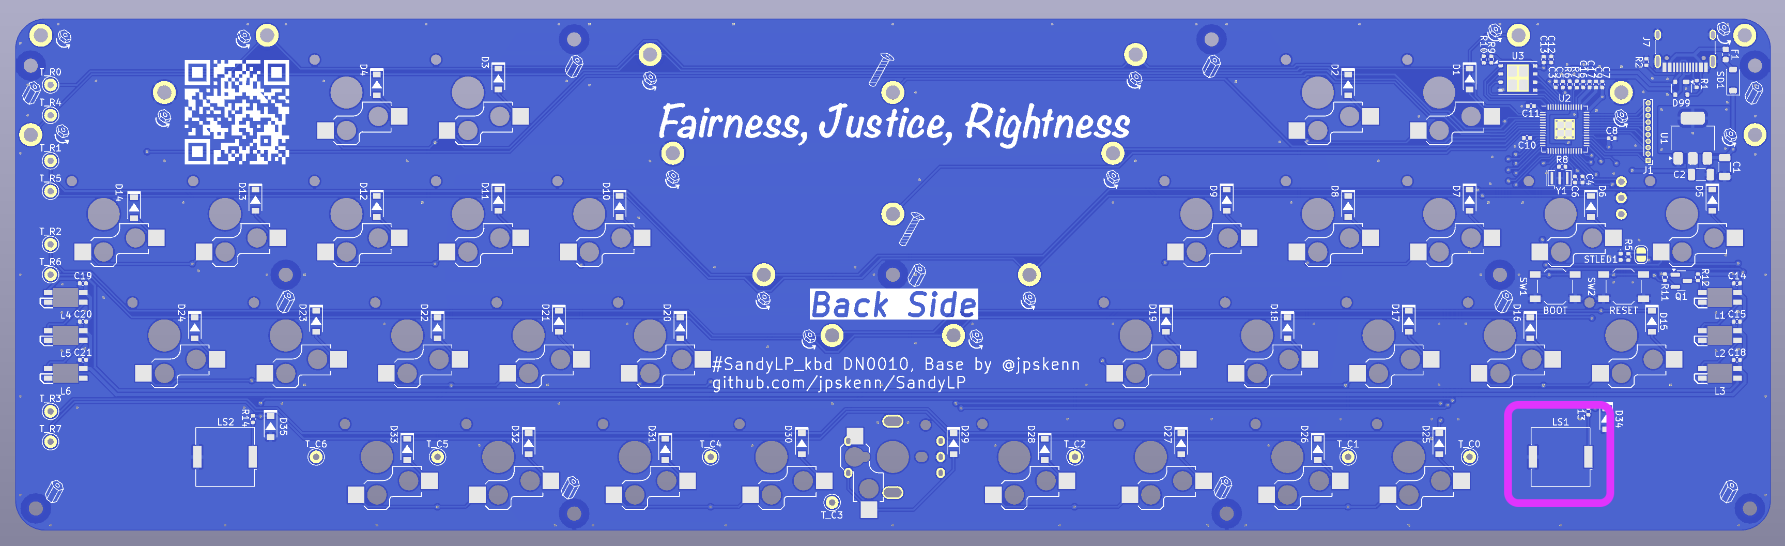
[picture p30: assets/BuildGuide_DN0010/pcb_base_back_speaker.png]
    

    スピーカーの左右にある金属端子部分を基板上のパッドに合わせてスピーカーを置き、スピーカー側面からはんだ付けします。  
    電気的な極性はないので、左右どちらの方向に取り付けてかまいません。

    💡ヒント：スピーカー上面の小さな穴から音が出てくるので、この穴がキーボード手前側にくるように取り付けると、音が聞こえやすくなるような気がします。

1. 【該当者のみ】おもて側から`ロータリーエンコーダ`を取り付ける。（1個）

    条件：ロータリーエンコーダを使用する場合

    取り付け場所：おもて側 最下行中央部

    **☠️危険：ロータリーエンコーダは「おもて側」からはめ込みます。**

    うら側からはんだ付けします。  

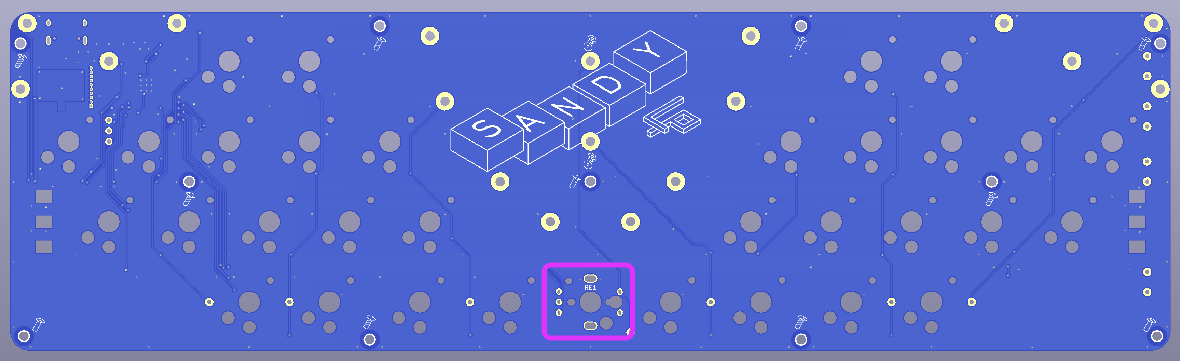
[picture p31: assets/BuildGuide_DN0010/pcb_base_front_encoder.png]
    

### 基板へのネジ止めとゴムシート貼り

**☠️危険：ネジやナットを締めこむ際は、少し抵抗を感じて「クククッ」と止まったあたりで締めこむのをやめます。**
**「ギュゥギュゥ」と締めこみすぎると、そのうち基板が物理的に破壊されます。**

💡ヒント：ネジ穴の隣には、その場所に取り付ける「ネジ」・「スペーサー」・「ナットとワッシャー」などのアイコンが描かれています。  
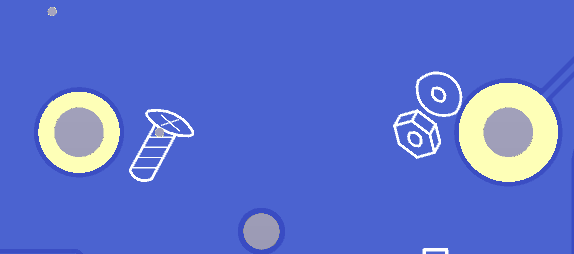
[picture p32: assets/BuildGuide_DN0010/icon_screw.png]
ネジ穴の印
  

#### 基板Topへのゴムシート貼り

1. `基板Top`うら側から、`小さな薄いゴムシート`を貼る。（6個）

    各種パーツやネジ穴に重ならない位置へ、フォームを貼ります。  
    少し曲げたり、一部をカットしてから貼ってもかまいません。

    貼り付け例  
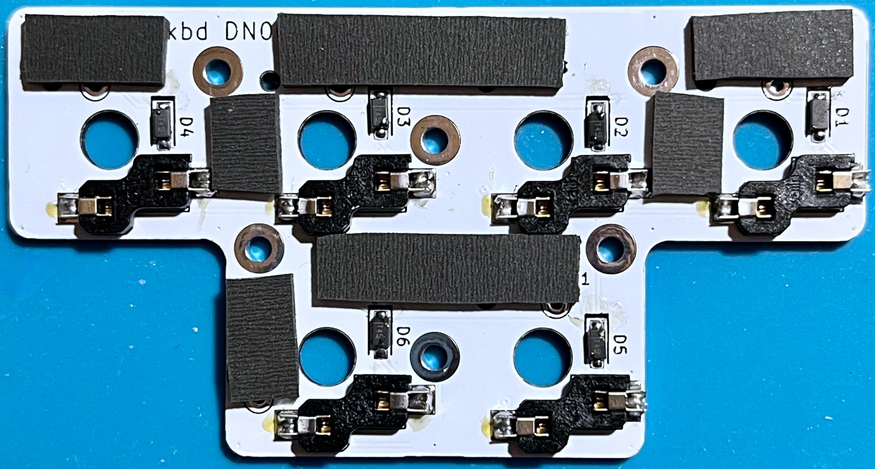
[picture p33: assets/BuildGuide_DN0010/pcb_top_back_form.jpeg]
    

#### 基板Mid中央へのネジ止めとゴムシート貼り

1. `基板Mid中央`のうら側から、`長いスペーサー`を`短いネジ（3mm）`でとめる。（4箇所）

    ```text
    長いスペーサー（3.5mm）
    ↑
    －－ 基板Mid中央 －－
    ↑
    短いネジ（3mm）
    ```

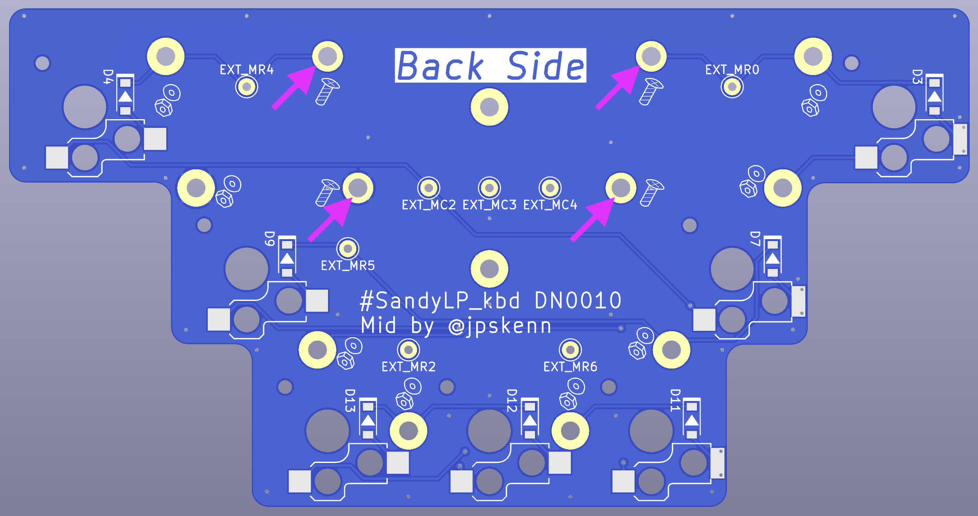
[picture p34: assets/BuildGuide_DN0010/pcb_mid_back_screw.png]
基板Mid中央 うら側ネジ止め箇所
    

1. おもて側から、`ワッシャー`を挟んだ`ナット`を`長いネジ`でとめる。（8箇所）

    ```text
    長いネジ（6mm）
    ↓  
    －－ 基板Mid中央 －－  
    ↓  
    ワッシャー  
    ↓  
    ナット
    ```

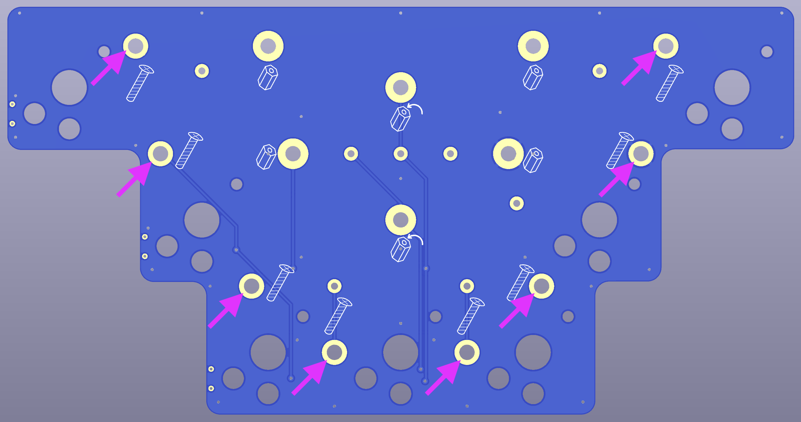
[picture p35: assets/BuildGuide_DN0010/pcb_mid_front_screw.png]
基板Mid中央 おもて側ネジ止め箇所
    

1. うら側の空いたスペースに`細くて薄いゴムシート`を貼る。

    **☠️異なる厚さのゴムシートを貼ると、正しく組み立てられません。**

    防振と打鍵感向上のため、各種パーツやネジ穴に重ならない位置へ、ゴムシートをはさみなどで切断して貼ります。  
    貼り付け位置は、以下のとおりです。

    ゴムシート貼り付け位置  
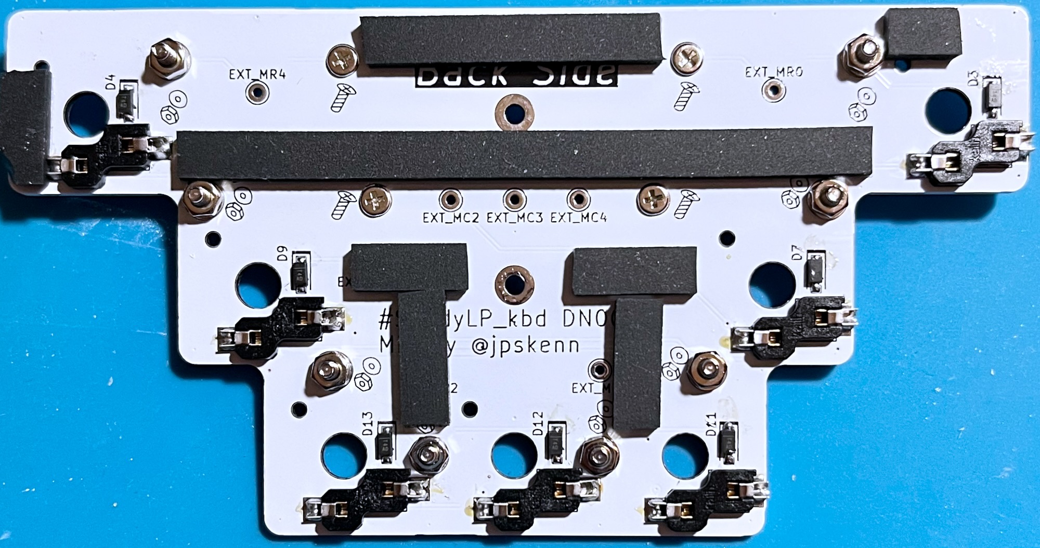
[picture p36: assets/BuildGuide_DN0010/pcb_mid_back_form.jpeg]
    

#### 基板Mid左右へのネジ止めとゴムシート貼り

1. `基板Mid左右`のおもて側から、`ワッシャー`を挟んだ`ナット`を`長いネジ`でとめる。（左右それぞれ4箇所、計8箇所）

    **☠️危険：中央部分のネジ穴と隣のソケット用パッドが近いので、ワッシャーをなるべくパッドから離すような気持ちで取り付ける。**

    ```text
    長いネジ（6mm）
    ↓  
    －－ 基板Mid左右 －－  
    ↓  
    ワッシャー  
    ↓  
    ナット
    ```

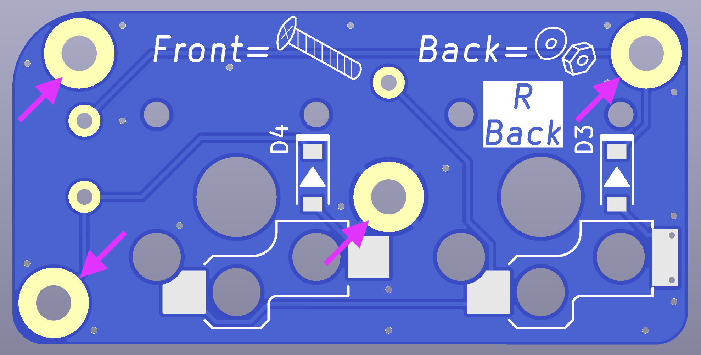
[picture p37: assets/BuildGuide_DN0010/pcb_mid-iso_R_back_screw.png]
    

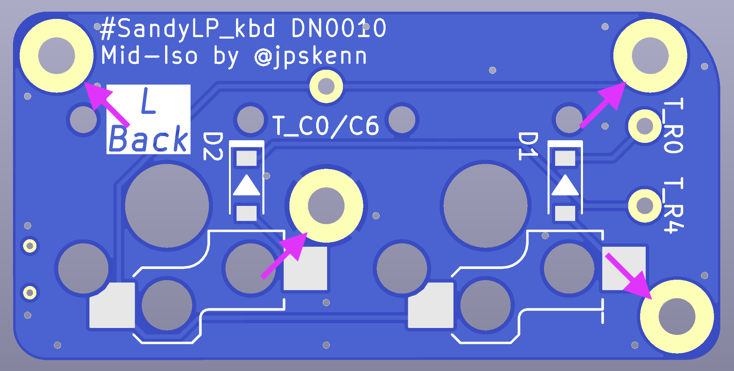
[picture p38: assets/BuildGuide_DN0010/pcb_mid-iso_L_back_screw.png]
    

1. うら側の空いたスペースに`細くて薄いゴムシート`を貼る。

    **☠️危険：異なる厚さのゴムシートを貼ると、正しく組み立てられません。**

    ゴムシート貼り付け位置  
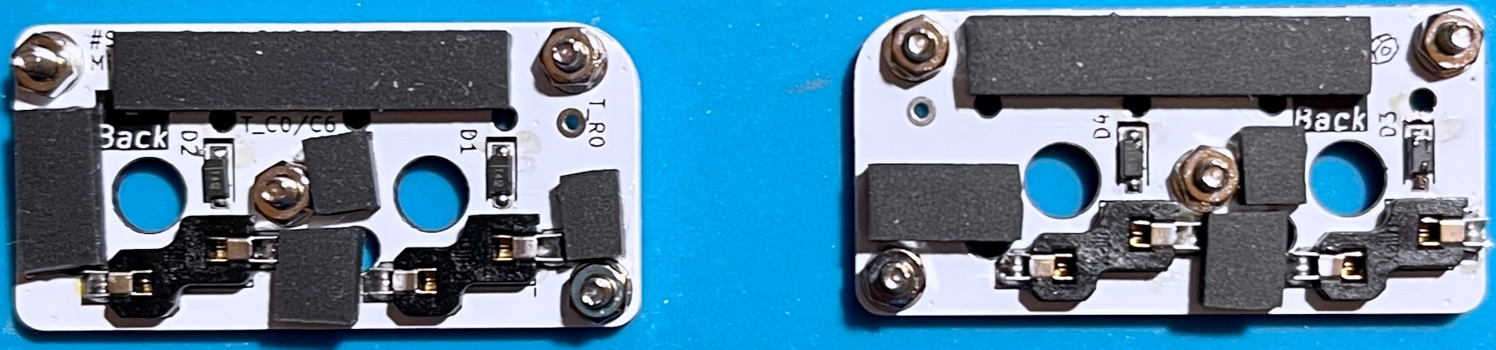
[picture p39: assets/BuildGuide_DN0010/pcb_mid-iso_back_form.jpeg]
    

#### 基板Baseへのネジ止めとゴムシート貼り

1. `基板Base`のおもて側から、`短いスペーサー`を`短いネジ（2mm）`でとめる。11箇所）

    **☠️危険：この手順のみ`短いネジ（2mm）`を使用します。**

    ```text
    短いネジ（2mm）
    ↓  
    －－ 基板Base －－  
    ↓  
    短いスペーサー（3mm）
    ```

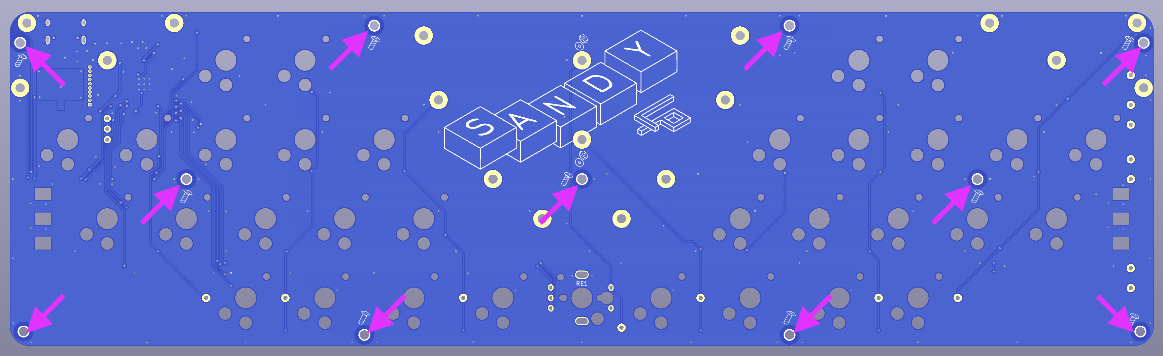
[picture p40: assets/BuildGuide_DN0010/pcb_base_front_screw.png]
基板Bass おもて側ネジ止め箇所
    

1. うら側から、`ワッシャー`を挟んだ`ナット`を`長いネジ`でとめる。（2箇所）

      ```text
      ナット
      ↑
      ワッシャー  
      ↑
      －－ 基板Base －－  
      ↑
      長いネジ（6mm）  
      ```

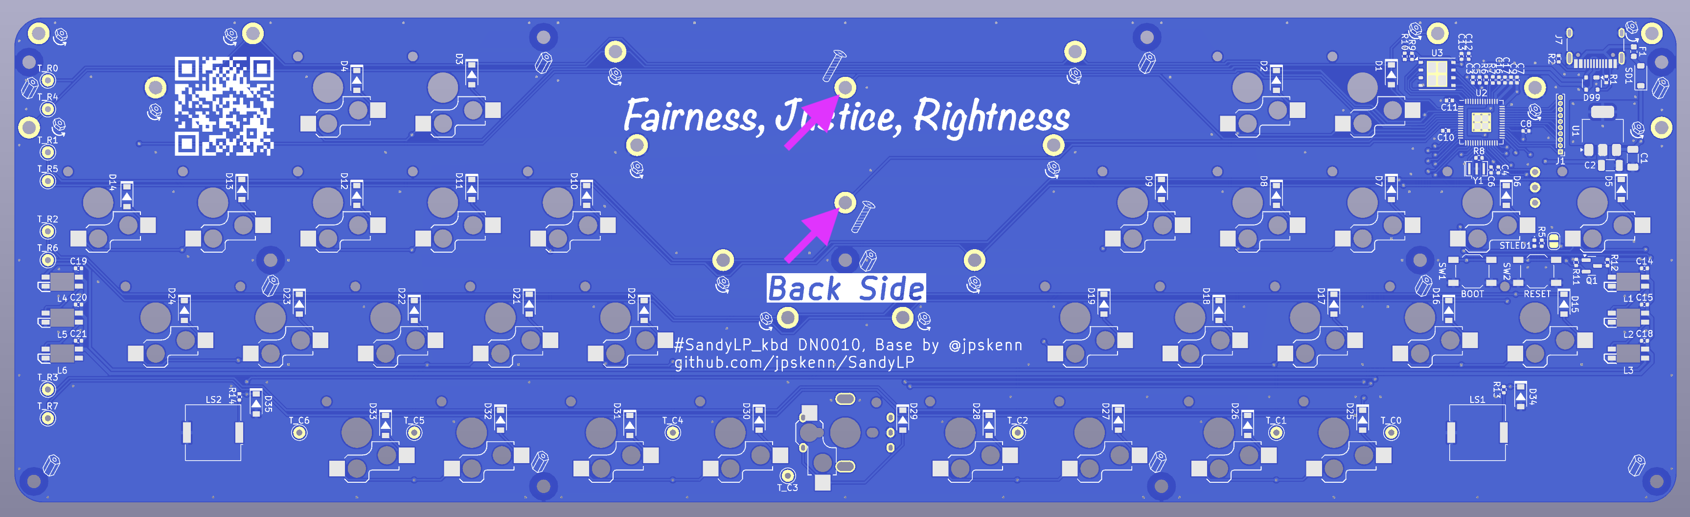
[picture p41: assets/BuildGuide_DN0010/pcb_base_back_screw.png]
基板Baseうら側ネジ止め箇所（長いネジ）
    

1. うら側から、`細くて分厚いゴムシート`を貼る。

    **☠️危険：異なる厚さのゴムシートを貼ると、正しく組み立てられません。**

    ゴムシート貼り付け位置  
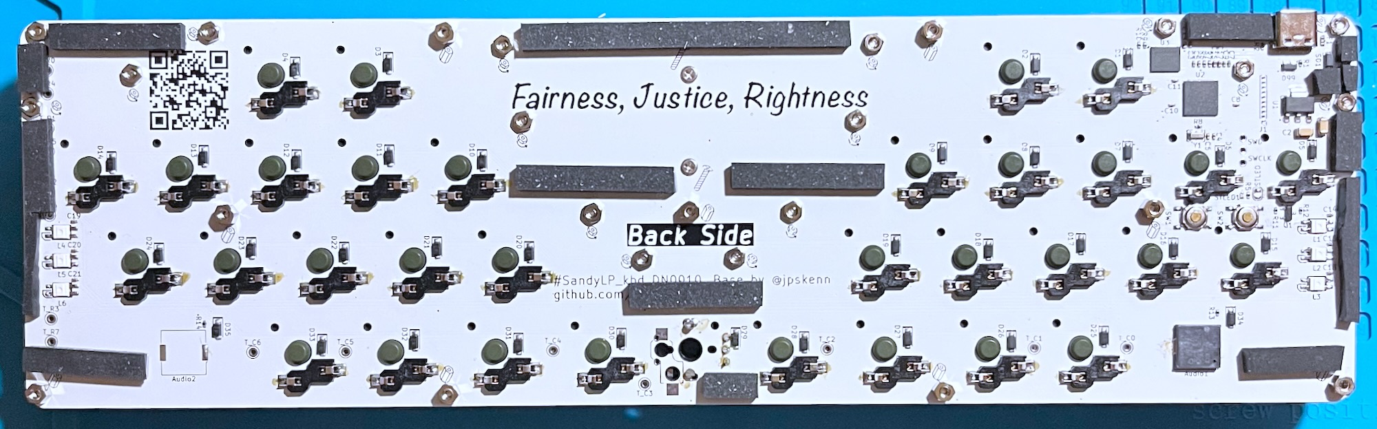
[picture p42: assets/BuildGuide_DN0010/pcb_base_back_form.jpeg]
    

### スイッチプレートへのゴムシート貼り

**☠️危険：異なる厚さのゴムシートを貼ると、正しく組み立てられません。**

`すべてのスイッチプレート`の裏面に`太くて薄いゴムシート`を貼ります。  
スイッチプレートの細い箇所には、ゴムシートを半分、または1/3の幅に切断してから貼るようにします。  
貼り付け位置は、以下のとおりです。

ゴムシート貼り付け位置  
Base用スイッチプレート  
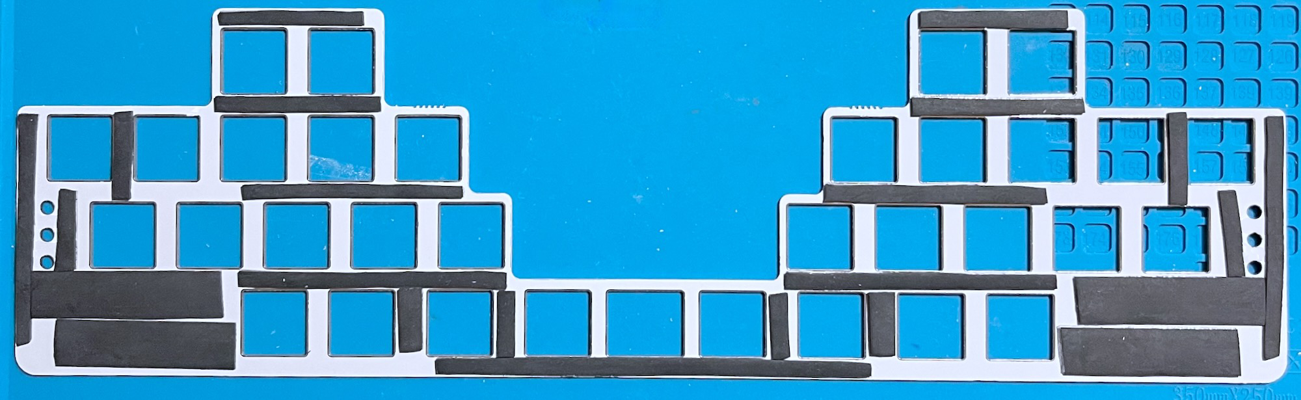
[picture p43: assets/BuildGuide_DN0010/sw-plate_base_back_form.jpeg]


Mid中央用スイッチプレート  
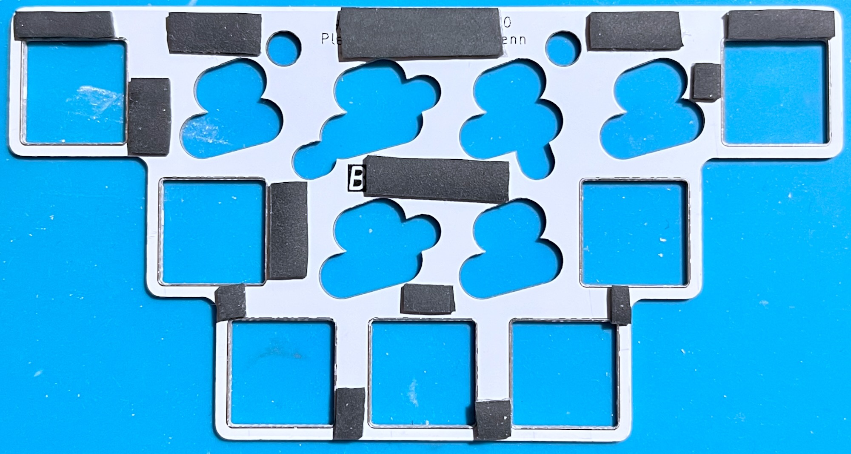
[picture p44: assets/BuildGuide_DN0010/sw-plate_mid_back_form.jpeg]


Mid左右用スイッチプレート  
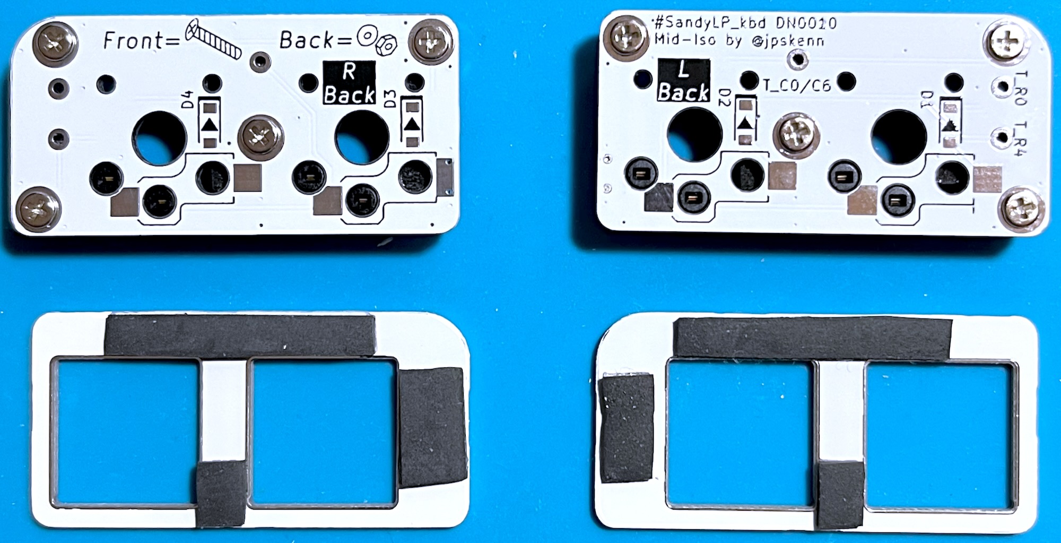
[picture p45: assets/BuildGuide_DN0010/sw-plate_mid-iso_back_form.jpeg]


Top用スイッチプレート  
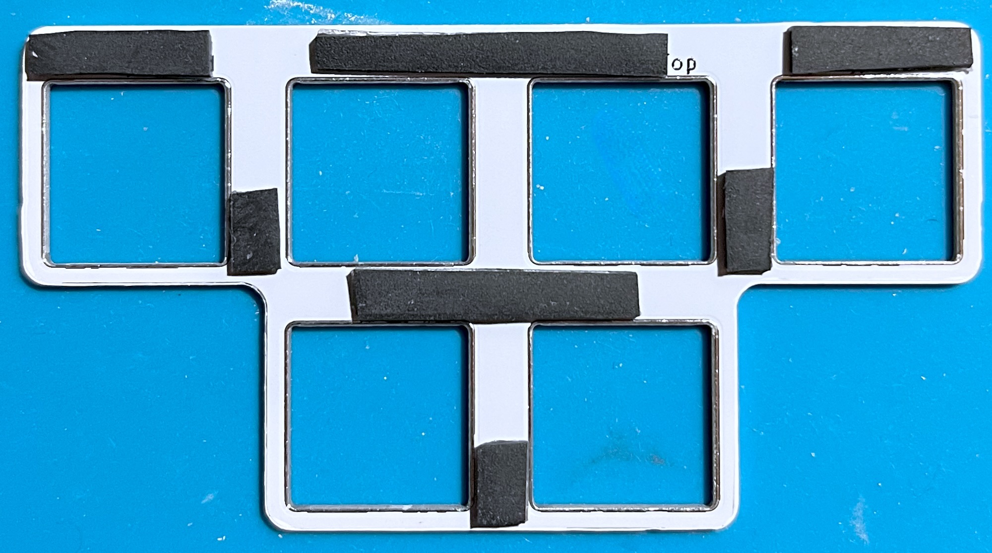
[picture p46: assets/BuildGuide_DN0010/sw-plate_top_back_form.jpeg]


【こだわり作業】`Base用スイッチプレート`うら側のLED穴へ、`プラ板（乳白）`を両面テープで貼り付けます。

### 基板とスイッチプレートをひとつに組み合わせて、スイッチを取り付ける

**☠️危険：ネジやナットを締めこむ際は、少し抵抗を感じて「クククッ」と止まったあたりで締めこむのをやめます。**

1. `基板Base`と`基板Mid中央`を組み合わせる。

    それぞれのネジ穴にはまるように重ね合わせます。  

    `基板Base`のうら側から、`基板Mid中央`のネジを`ナット`で止めます。（8箇所）

    ```text
    －－ 基板Mid中央 －－  
    ↓  
    －－ 基板Base －－  
    ↑  
    ナット
    ```

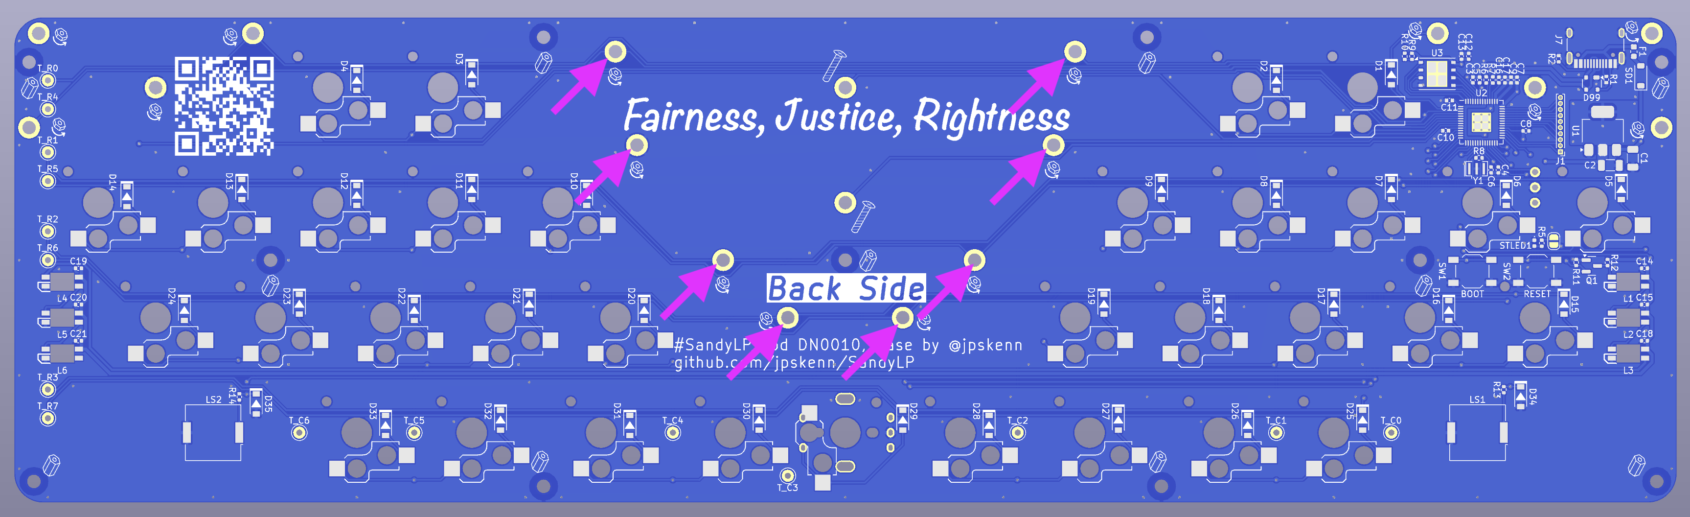
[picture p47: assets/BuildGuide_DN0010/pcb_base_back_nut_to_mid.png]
    

    `基板Mid中央`のおもて側から、`長いスペーサー`を取り付けます。（2箇所）

    ```text
    長いスペーサー(3.5mm)
    ↓
    －－ 基板Mid中央 －－  
    ↑  
    －－ 基板Base －－  
    ```

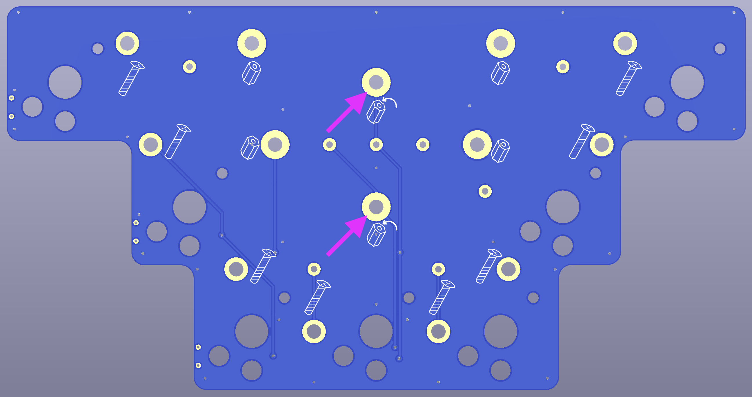
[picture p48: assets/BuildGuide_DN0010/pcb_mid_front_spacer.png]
基板Mid中央 おもて側スペーサー取り付け箇所
    

1. `基板Base`と`基板Mid左右`を組み合わせる。

    ネジ穴にはまるように重ね合わせます。  

    `基板Base`のうら側から、`基板Mid左右`のネジを`ナット`で止めます。（ぞれぞれ4箇所、計8箇所）

    **☠️危険：1箇所、ナット付近に小さなパーツが配置されているところがあります。レンチ等が小さなパーツに当たらないようにします。**

    ```text
    －－ 基板Mid左右 －－
    ↓
    －－ 基板Base －－
    ↑
    ナット
    ```

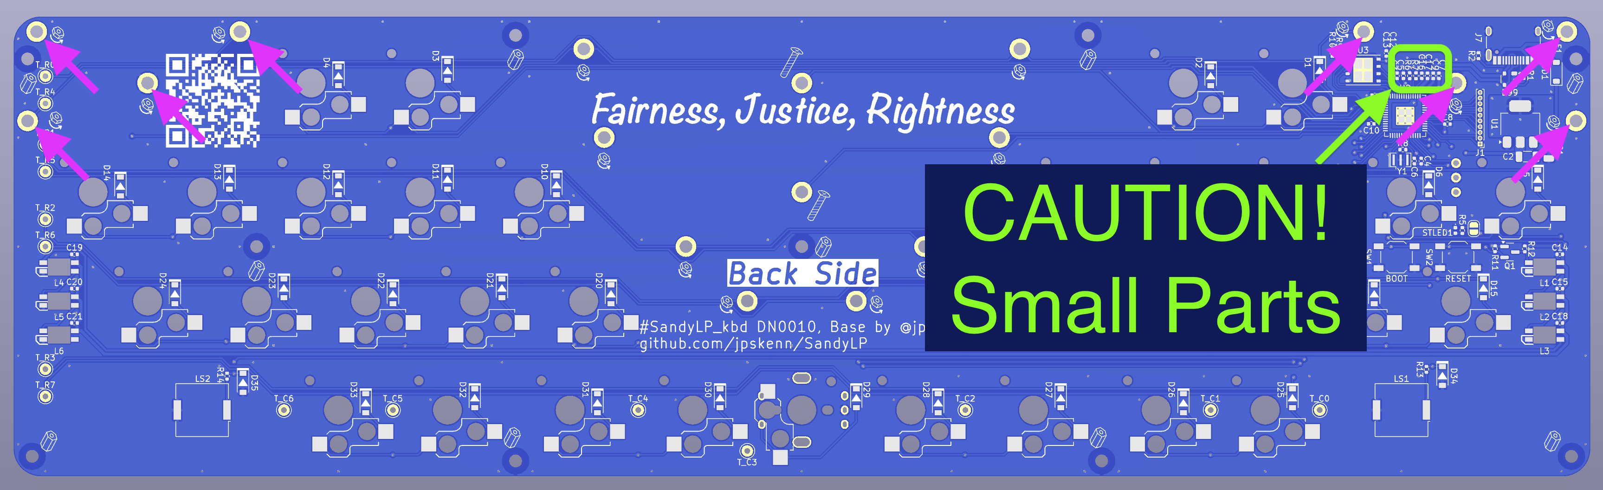
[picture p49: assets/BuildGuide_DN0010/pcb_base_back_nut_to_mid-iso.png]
    

1. `Mid中央用スイッチプレート`とスイッチを取り付ける。

    スイッチの端子が曲がっていないことを確認します。  
    スイッチプレートを基板の形に合わせて重ねます。  
    スイッチの端子と基板のソケットの方向を確認します。  
    スイッチプレートを挟みながら、スイッチをまっすぐに押し込んで取り付けます。  

    メモ：  
    スイッチによっては、スイッチプレートへのはめ込みがきついものがあります。  
    Kailh Lofree FLOW GHOSTはけっこうきつく、Kailh Deep Sea Silent MINIは適度な具合でした。

    ```text
    －－ スイッチ －－
    ↓
    －－ Mid中央用スイッチプレート －－
    ↓
    －－ Mid中央基板 －－
    ```

    スイッチがプレートにぴったりとはまっていることを確認します。  

    以下の写真はスイッチがプレートにはまっておらず、プレートが押し下げられた不正な状態です。  
    プレートの端を指で持ち上げたりして、スイッチをプレートにぴったりとはめ込みます。  
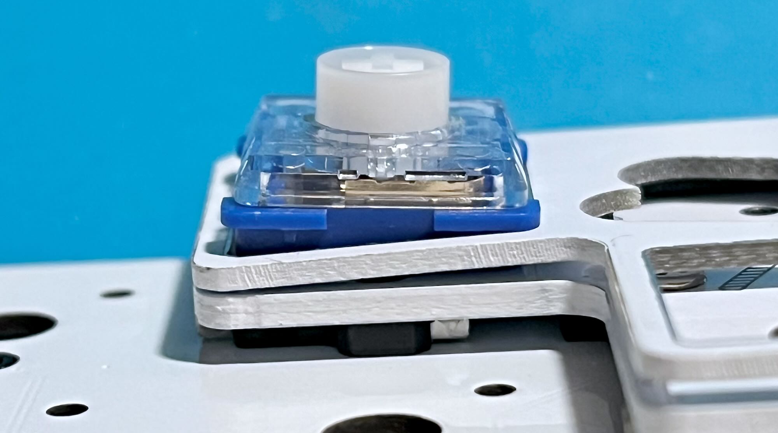
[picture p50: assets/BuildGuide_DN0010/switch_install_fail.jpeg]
スイッチがプレートから浮いている不正な状態
    

1. `基板Top`と`基板Mid中央`を組み合わせる。

    間に`Mid中央用スイッチプレート`をはさむようにして、ネジ穴にはまるように重ね合わせます。  

    `基板Top`のおもて側から、`基板Mid中央`のスペーサーを`短いネジ（3mm）`で止めます（6箇所）

    ```text
    短いネジ（3mm）
    ↓  
    －－ 基板Top －－
    ↑  
    －－ 基板Mid中央 －－
    ```

1. `基板Base`に、`Base用スイッチプレート`と`スイッチ`を取り付ける。

    💡ヒント：`Base用スイッチプレート`は、ロゴ入りのおもて面と、無地のうら面のどちら向きでも使えるリバーシブル仕様です。  
    キーキャップを取り付けるとプレートに書かれた文字はほとんど見えなくなりますが、小さ目のキーキャップを使う場合は少し目立ってしまうかもしれません。

    ```text
    スイッチ
    ↓
    －－ Base用スイッチプレート －－
    ↓
    －－ Base基板 －－
    ```

1. `基板Mid左右`に、`Mid左右用スイッチプレート`と`スイッチ`を取り付ける。

    ```text
    スイッチ
    ↓
    －－ Mid左右用スイッチプレート －－
    ↓
    －－ Mid基板 －－
    ```

1. `基板Top`に、`Top用スイッチプレート`と`スイッチ`を取り付ける。

    ```text
    スイッチ
    ↓
    －－ Top用スイッチプレート －－
    ↓
    －－ Top基板 －－
    ```

### 動作確認する

1. [Remap](https://remap-keys.app/)の`Test Matrix Mode`を使用して、すべてのキースイッチが正常に反応するか確認する。

    異常がある場合は、原因を調査して修正します。

### ボトムプレートを取り付ける

1. 組み合わせた基板を裏返し、USBコネクタの切り欠き部分の位置を合わせながら`ボトムプレート`を乗せる。

1. `ボトムプレート`うら側から、`短いネジ（3mm）`で止める。（11箇所）

    ```text
    －－ 組み合わせた基板 －－
    ↓  
    －－ ボトムプレート －－
    ↑
    短いネジ（3mm）
    ```

    ボトムプレートうら側からのネジ止め箇所

1. ボトムプレートのうら側から、ゴム足を貼る。

### キーキャップを取り付ける

1. `キーキャップ`を取り付ける。

1. 【該当者のみ】`ロータリーエンコーダ`の`ノブ`を取り付ける。

    条件：ロータリーエンコーダを使用する場合

以上で組み立て完了です。
完成

## ユーザーズマニュアル・カスタマイズガイド

SandyLPの機能や関連情報、また、自分の好みにカスタマイズする方法について説明します。

### 初期ファームウェアの機能と設定値

出荷時に書き込まれている初期ファームウェアの機能と設定値を説明します。

- QMKバージョン

  0.26.3

- キーマップ書き換えツールのRemapに対応（VIA有効化）。

- レイヤー構成とレイヤーインジケータLEDの色

  レイヤー0から7まで、8個のレイヤーが使用できます。  
  LEDは左右とも同じパターンで点灯します。`－`は元のレイヤー色、`×`は消灯を意味します。

    | No. | レイヤー名 | 主なキー割り当て | LEDの色 上, 中, 下 |
    | :-: | :-- | :-- | :-: |
    | 0 | ベースレイヤー #1 | [SemiErgo](https://github.com/mtei/SemiErgo_Layout)風 英語配列, Mac向けモディファイア | 白, 白, 白 |
    | 1 | ベースレイヤー #2 | ↑ | 青, 青, 青 |
    | 2 | ベースレイヤー #3 | テンキー | 黄, 黄, 黄 |
    | 3 | Lower #1 | ファンクションキー<br>記号<br>音量コントロール | －, 緑, － |
    | 4 | Lower #2 | ↑ | －, 黄緑, － |
    | 5 | Raise #1 | 数字行<br>記号<br>カーソル移動 | －, 水, － |
    | 6 | Raise #2 | ↑ | －, 紫, － |
    | 7 | Adjust | ベースレイヤー切り替え<br>LED、Audio等の設定<br>スクロールロックなど | －, 赤, － |
    | 番外| CapsLock | n/a | －, －, 赤紫 |

- ハードウェア機能

  - ロータリーエンコーダ
    プッシュボタン付き1個に対応。

  - スピーカー
    スピーカー1個に対応。

- その他

  - デフォルトレイヤーの変更はEEPROMに保存されます
    `DF(0)`、`DF(1)`、`DF(2)`を使ったデフォルトレイヤーの変更はEEPROMに保存され、キーボードの電源が失われても変更したレイヤーで起動します。

  - キーボードの起動音（＝スピーカー機能）をON/OFFする

    `AdjustレイヤーのZ`を押すごとに、ON/OFFが切り替わります。  
    この操作により、スピーカー機能自体がON/OFFされるので、ピコピコ音や音楽鍵盤機能もOFFになります。

  - キー押下時のピコピコ音をON/OFFする

    `AdjustレイヤーのX`を押すごとに、ON/OFFが切り替わります。  
    なお、キーボードの起動音（＝スピーカー機能）がOFFになっているときは、ピコピコ音は鳴りません。

  - レイヤーインジケータの表示状態を切り替える

    レイヤーインジケータの表示状態は、以下の4通りの表示に切り替えることができます。

    - 左右両方に表示
    - 左のみ表示
    - 右のみ表示
    - インジケータ表示なし

    表示状態は`AdjustレイヤーのO（オー）`を押すごとに切り替わり、表示状態はEEPROMに保存されます。

    なお、インジケータ表示がない場所には、QMKの[RGB Lighting](https://docs.qmk.fm/features/rgblight)が表示されます。  
    LEDを完全に消灯するには、`AdjustレイヤーのL`を押して、RGB LightingをOFFにします。

  - レイヤーインジケータの明るさを調整する

    レイヤーインジケータの明るさは、RGB Lightingの明るさに連動しています。

    明るさを調整するには、  
    （RGB LightingがOFFのときは、`AdjustレイヤーのL`を押してONにしてから）
    `AdjustレイヤーのI`または`K`で明るさを調整します。

    調整が終われば、もういちど`AdjustレイヤーのL`を押してRGB LightingをOFFにしてもかまいません。

### SandyLP関連ファイル

このキーボードに関連するファイルです。  

- ビルド済みファームウェア（QMK バージョン 0.26.3）： [sandy_lp_remap.uf2](../Firmware/sandy_lp_remap.uf2)

- ビルド済みファームウェア（Vial bb7961c）： [sandy_lp_vial.uf2](../Firmware/sandy_lp_vial.uf2)

- ファームウェアのソース

    私がQMKからフォークしたリポジトリ[https://github.com/jpskenn/qmk_firmware](https://github.com/jpskenn/qmk_firmware)の、[develop_SandyLP_QMK_0.26.3](https://github.com/jpskenn/qmk_firmware/tree/develop_SandyLP_QMK_0.26.3)ブランチ内、`keyboards/sandy_lp/`に配置しています。  

    また、Vial版については、私がvial-qmkからフォークしたリポジトリ[https://github.com/jpskenn/vial-qmk/](https://github.com/jpskenn/vial-qmk/)の、[develop_local](https://github.com/jpskenn/vial-qmk/tree/develop_local)ブランチ内、`keyboards/sandy_lp/`に配置しています。

- 基板等の設計ファイルやドキュメント、Remapの定義ファイルなど

    [SandyLPリポジトリ](https://github.com/jpskenn/SandyLP)のリリース[DN0010](https://github.com/jpskenn/SandyLP/releases/tag/DN0010-001)にまとめてあります。

### ファームウェアを書き換える

**☠️危険：作業に失敗するとキーボードが機能しなくなることがあります。内容を理解した上で、自己責任でおこなってください。**

1. 以下の操作をおこない、SandyLPをマスストレージデバイスとしてPCやMacに認識させます。

    1. USBケーブルが接続されている場合は、ケーブルを抜く。
    1. キーボードうら側の`SW1`ボタン（文字が見えにくいので写真を参照）を押したまま、USBケーブルを差し込む。  
        ケーブルを差し込んだら、ボタンから手を離す。  
    BOOTSELボタン
    1. PCやMacで、マスストレージの`RPI-RP2`として接続・認識されているか確認する。

1. 書き込みたいファームウェアのUF2ファイル（example.uf2）を、先ほどの`RPI-RP2`へコピー＆ペーストなどの操作で保存します。

以上で書き込み作業は完了です。  

UF2ファイルを保存すると、勝手に（自動的に）マスストレージの接続が解除され、キーボードとして起動します。  
Macでは「ディスクの不正な取り出し」に関するメッセージが表示されますが、特に問題ないので無視してかまいません。（Windowsは知りません）

### EEPROMを消去して初期状態に戻す

EEPROMに記録されているデータを消去し、初期状態に戻す方法について説明します。  

キーマップやLEDの表示モードなどのEEPROMに記録されているデータを消去し、初期状態に戻すことができます。  

1. USBケーブルを接続している場合は、ケーブルを抜きます。

1. キーボードの左上のキーを押したまま、USBケーブルを差し込みます。

1. ケーブルを差し込んで、1、2と数えてから、キーを押していた指を離します。
    キーボードが、PCやMacでマスストレージデバイスとして認識されます。

1. 5秒ほど待ってから、USBケーブルを抜きます。

1. USBケーブルを差し込みます。
    キーボードが起動します。

以上の操作でEEPROMが消去され、初期状態に戻ります。

### 電源LEDを点灯しないようにする

`基板Base`うら側の電源LEDは、ファームウェアの動作状況に関わらず、USBコネクタからの電源によって点灯しています。

電源LEDを点灯しないようにするには、次の手順をおこないます。  

1. `基板Base`うら側、`STLED`がはんだでジャンパされ、2つのパッドがつながった状態になっています。  
1. はんだごてを軽く当ててはんだを一部取り除き、つながっていない状態にします。

電源LEDを点灯させる場合は、`STLED`をはんだでジャンパして、つながった状態にします。

### キーキャップの選び方

このキーボードで使用するChoc V2スイッチには、十字形状の穴をもつ、いわゆるCherry MXに互換性のあるキーキャップ（以降、MX用キーキャップと言う）を取り付けることができます。  

#### キーキャップセット

GMKやePBT等のいわゆるBase Kitを使用すると、見た目的にも質感的にも良い具合に仕上げることが可能です。  
また、英語104キーのセットでもそれなりに使える感じに仕上がります。

キーキャップガイド

#### キーキャップとスイッチの組み合わせ

Choc V2などのロープロファイルなスイッチに合わせて設計されていないMX用キーキャップは、押下時にスイッチやスイッチプレートに当たり、干渉してしまうことがあります。  
また、Choc V2スイッチは販売時期やシリーズによってトップハウジングの形状が異なっているため、干渉を避けるにはキーキャップとスイッチの組み合わせが重要となります。

組み合わせについては、74thさんの「[Kailh x Lofree Shadowシリーズ、Kailh Choc V2(Deep Sea Silent MINI)で使えるキーキャップを調査した](https://74th.hateblo.jp/entry/chocv2-compatible-keycap)」や、以下の私自身が実際に試した結果を参考にしてください。（干渉しないことを保証するものではありません）

私が試した組み合わせ結果

| スイッチ | キーキャップ | 干渉の有無 | 使用感 |
| :-- | :-- | :-- | :-- |
| Kailh Lofree FLOW GHOST | ePBT, Cherry, Less But Better | プレート干渉はほぼなし。スイッチに当たっている感じがある。 | スイッチ自体の底打ち衝撃と干渉の音が若干ズレるような感じがあり、あまり気持ちよくない。 |
| Kailh Lofree FLOW GHOST | ENJOYPBT DOUBLESHOT ABS, Cherry, Dolch Yellow | プレート干渉あり。スイッチ干渉不明（スイッチに当たる前にプレートに当たっている） |  |
| Kailh Lofree FLOW GHOST | Keyreative, KAT, Space Cadet | プレート干渉なし。スイッチ干渉あり。 | スイッチには干渉しているが、スイッチ自体の底打ち衝撃と干渉の音が一体化しているためあまり気にならず、普通に使える。ePBT Cherryとは感触が異なる。 |
| Kailh Lofree FLOW GHOST | Signature Plastics, G20, individual | プレート干渉なし。スイッチ干渉あり。 | スイッチには干渉しているが、スイッチ自体の底打ちと一体化している。使えないこともない。 |
| Kailh Lofree FLOW GHOST | NuPhy, nSA, BOW | 干渉なし。 |  |
| Kailh Deep Sea Silent MINI | Signature Plastics, DSS, Solarized Dark | プレートへのクリアランスはぎりぎりで、数個のキーで干渉あり（個体差？）。スイッチ干渉なし。 | 一部気になるところがあるが、基本的には問題なし。日常的に使用中。 |
| Kailh Deep Sea Silent MINI | Signature Plastics, G20, individual | プレート干渉なし。スイッチ干渉あり。 | 押下時コツコツという小さい音と感触があり、サイレントではなくなる。 |
| Kailh Deep Sea Silent MINI | ePBT, Cherry, EPBT x Openkey Less but better | 干渉なし。 | 50個に1個くらいの割合でキーキャップと干渉するスイッチがある（内部のダンパーがずれている？）ので、スイッチを5個くらい多めに買っておいて選別するとよい。日常的に使用中。 |

キースイッチとキースイッチの組み合わせ

## サービスマニュアル

基板の出荷準備作業などについてのメモ。

### パーツリスト

| スイッチ | キーキャップ | 結果 |
| :---- | :-----: | :---- |
| スイッチ<br>RS-187R05A2-DSMTRT | 2 ||

### 基板セットアップ

1. Base用スイッチプレート：捨て基板を切り離す。

    切り離す際にプレートが歪まないよう注意。

1. 基板Base：基板上下の製造タブをVカットに沿って切り離し、切断面を軽くやすりがけする。

1. 基板Base：`STLED`をジャンパして、USBコネクタを接続し、`STLED1`が緑に点灯することを確認する。

    点灯しない場合は、電源系、USBコネクタ等の問題を検査。

1. 基板Base：うら側の`SW1`と`SW2`へスイッチを取り付ける。

1. ファームウェアを書き込む

    1. `SW1`を押下しながらUSBケーブルを差し込む、またはUSBケーブルが差し込まれた状態で`SW1`を押下したまま`SW2`を押下して離し、`SW1`を離す。
        コンピュータ上で`RPI-RP2`というドライブが認識される。

    1. QMKコマンド、またはファイラー等を使ってファームウェアのファイルを`RPI-RP2`ドライブへ配置。

        ドライブの接続が解除され、USBデバイス（キーボード）として起動。

    1. Remapでスイッチソケットのパッドの反応を確認する

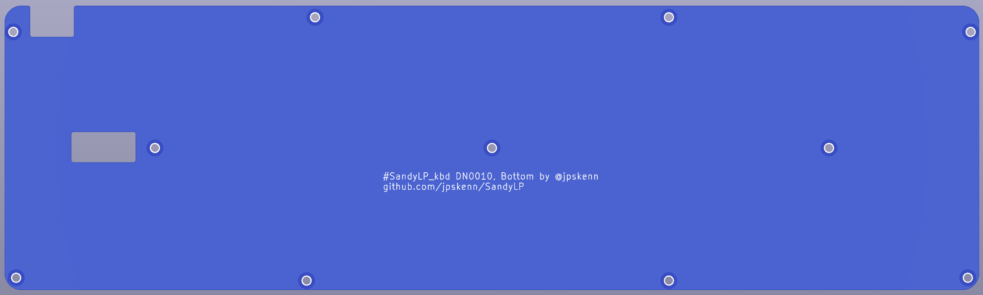
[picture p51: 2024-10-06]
assets/BuildGuide_DN0010/plate_bottom_front.png

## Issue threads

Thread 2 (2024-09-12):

DN0010仕様

jpskenn, 2024-09-12:
構造図

Base：1.2ｍｍ　全高を下げるため、1.6→1.2とする。
Mid：1.6mm　Sandyと同じ基板間隔（Base→Mid 3.6ｍｍ）にするため、1.6ｍｍ。また、1.2ｍｍだとスイッチの真ん中足（3.3mm）が2.1mm飛び出すため、2ｍｍスペーサーでは足りず、Baseに当たってしまう。
Top:：1.6mm　Sandyと同じ基板間隔（Mid→Top 5.0ｍｍ）にするため、1.6ｍｍ。
スイッチプレート：すべて1.2mm（1mmゴムシートで基板間を埋める）

図外：各基板間（Base→Mid 2.0ｍｍ、Mid→Top３．４ｍｍ

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

jpskenn, 2024-09-13:
レイアウト
http://www.keyboard-layout-editor.com/#/gists/29f5da09ffa69ab85efa4c68b556282b
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

jpskenn, 2024-09-13:
ハードウェア機能
- MCU　RP2040
- USB-C
- ロータリーエンコーダ　最下行中央に1個
- LED　左右3個ずつ、計6個。※もうちょい検討中
- Audioスピーカー　1個（実験的に2個目も設置可能）[QMKのAudio機能](https://docs.qmk.fm/features/audio)に対応

jpskenn, 2024-09-23:
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

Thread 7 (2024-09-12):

基板外形のデザイン

jpskenn, 2024-09-12:
GH60型ケースに収める必要がなくなったので、すこし縁があったりしてもよい。
基本的には長方形で、何かするのは上下左右の余白と、コーナーのRくらい。
斜めなところをつけると（例えば親指部分だけ飛び出すとか）、ゴム足で角度を付けるのがやりにくい。

jpskenn, 2024-09-13:
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
上下左右に0.25uの縁をつける。
（Topとかどうなる？）
大きいようで大きくないRに。

jpskenn, 2024-09-14:
上下0.25uは手前に出過ぎている感じがするので、上下は0.125uに変更。

jpskenn, 2024-09-16:
もう少しRを大きくしたかったが、USBコネクタ付近のネジなどがあるため、今回はこれくらいで。
手前だけRを大きくすることもできるが、なんかイマイチ？
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

Closed 2024-09-16.

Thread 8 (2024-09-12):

基板間を何かしらの素材で埋める

jpskenn, 2024-09-12:
基板とスイッチプレートを全体的にソリッドな状態にしたいので、間の空間をなるべく埋めたい。

- 10×10の安いFR-4
- ゴムシート
- その他

jpskenn, 2024-09-16:
fr-4を挟むなら、固定方法が必要

jpskenn, 2024-09-20:
とりあえず以下を試す。
- ゴムシート　T2mm、T3mm
  https://jp.misumi-ec.com/vona2/detail/110300277050/?ProductCode=UNSEA3-5
- プレート用静音フォーム　T3.5mm
  https://talpkeyboard.net/items/65d5c2ad70810903b47c1593

jpskenn, 2024-10-01:
今のところ、
ゴムシート　T2mm、T3mm
https://jp.misumi-ec.com/vona2/detail/110300277050/?ProductCode=UNSEA3-5
で良い具合になっている。

T3.5mmのフォームは計算間違いだった。
Top基板はMid中央基板の上に配置されるので、Top→Mid間の3.5mm（スペーサー）から、Midプレート高の2.2mmをマイナスした1.3mmのフォームが必要。
とりあえず、kerowaのフォームが柔らかいので、3.5mmを1.3mmまで圧縮して使用している。
→何らかの代替が必要。

jpskenn, 2024-10-01:
T1.5mmで、これはどうか？やわらかめなので、1.3mmまで圧縮できそう。
イノアック
L32-1.5100-MT [マイクロセルウレタンロールPORON 黒 1.5×100mm×1M巻]
https://www.yodobashi.com/product/100000001004002514/

Closed 2024-11-28.

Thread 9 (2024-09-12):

LED個数、LED窓のデザイン、光線漏れ対策

jpskenn, 2024-09-12:
LEDは左右どちらかに、2個、または3個を配置。

右に見たい人や左に見たい人がいるとは思うが、両方に配置するのはダサい感じがする。
LED窓自体が半透明で見えてしまうので、どちらか片方だけに配置する。

LEDの個数は、自分としては2個あれば十分。
（実際には左右で同じ内容を表示していたが）今までは4個あり、今回は左右どちらか一方への配置にするので2個では少ない気がするので3個？
普通のキーボードにもCaps、NumLock、ScrLockの3つのLEDがあるので、それと合わせるという理由もつけてもよい。

光線漏れ対策として、Base基板のLEDまわりに何かをとりつけたい。
→スイッチプレートをゴムシートで支えるので、ゴムシートでよい。

jpskenn, 2024-09-13:
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
ドット、もしくは小さな四角のLED穴を、3個。
小さい穴なら、左右3個ずつでもよいかも。

jpskenn, 2024-09-16:
base用スイッチプレートをリバーシブルにするため、左右に同数つける。

jpskenn, 2024-09-16:
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
丸型、左右3個ずつ。

jpskenn, 2024-09-19:
LED窓のデザイン、縦に◯3個もよいけど、縦棒1本でもよいのでは？
スイッチプレート裏に貼り付けるゴムシートで、各LEDの光が混ざらないようになっているので。

jpskenn, 2024-10-01:
Base基板うら側のサイド部分から、LED枠の隙間から戻ってきた光が漏れるので、ここにも光線漏れ対策としてシートを張る必要あり。

jpskenn, 2024-12-01:
続きは
https://github.com/jpskenn/SandyLP/issues/24
でやるのでClose

Closed 2024-12-01.

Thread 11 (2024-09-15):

キーキャップの干渉

jpskenn, 2024-09-15:
Kailh Deep Sea MINIで、キーキャップの干渉をチェックした。

- DSS
  ハードヒットで、A行がうっすらスイッチに当たるかも。押下時、プレートまでコピー用紙数枚くらいのクリアランスしかなくてヒヤヒヤ。
- GMK Cherry
  ハードヒットでA行が確実に当たる。
- ePBT Cherry
  ハードヒットでA行ちょっと当たる。
- ENJOYPBT DOUBLESHOT ABS(Dolch Yellow) Cherry
  ハードヒットでA行当たる。
- KAT
  まったく当たらない。

ハードヒットは、ッターン！！みたいな上から振り下ろすような感じのこと。
普通の打鍵だと、大して気にならないレベル。
また、いずれも、プレートには当たらない。

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

jpskenn, 2024-09-15:
Kailh Lofree FLOW GHOST
- DSS スイッチ・プレートにめっちゃあたる
- ENJOYPBT DOUBLESHOT ABS(Dolch Yellow) Cherry　スイッチ・プレートにめっちゃ当たる
- XVX ダブルショット PBT キーキャップ　スイッチ・プレートにめっちゃ当たる

GMKは未チェックだが、DSSが当たるということは、GMKも当たると思われる。

jpskenn, 2024-11-08:
とりあえず試せるスイッチがないので、一旦クローズ。

Closed 2024-11-08.

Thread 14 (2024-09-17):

chocとmx両対応

jpskenn, 2024-09-17:
https://note.com/___a_o_i/n/nb0fc1756ac19?sub_rt=share_pw

jpskenn, 2024-10-01:
MXに対応するには、

- 両対応フットプリントに変更
- プレートを1.6mmに変更

で、いけそう？

jpskenn, 2024-10-07:
基板TopをMid中央用スイッチプレートの上に持ってくるので、無理な感じがするので、やめ。

Closed 2024-10-07.

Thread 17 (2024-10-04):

リバーシブルなスイッチプレートへの開発ナンバー表記

jpskenn, 2024-10-04:
キーキャップに隠れそうな所へ小さい文字で入れているが、これ以上文字を小さくするのはJLCPCBの制限に引っかかる。
キーキャップによっては、見えてしまうかもしれない。

二次元コード的なもので、もうちょい小さくできないか？

jpskenn, 2024-11-28:
今のところ、キーキャップ側からそんなに文字が見えない。
それほど問題ではないのでClose。

Closed 2024-11-28.

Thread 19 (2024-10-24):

Base基板、Base用スイッチプレート、LED窓を移動。

jpskenn, 2024-10-24:
LED窓を移動する。

- もうちょい内側へ移動する。
  3Dプリントのケース使用時、DN0010,DN0011の位置では、ケースのハイプロとキーキャップの間でセンタリングされていないので見た目がイマイチ。
- LED窓を上下で寄せる。
  LEDの手前側（R5）がハイプロになるため、LEDがハイプロで見えなくなるのを避ける。
  なるべくLED3個にしておきたいが、おさまりが悪いようならLED2個でもよい。
  ※LEDの位置はR3の行内で上下中央寄せにする。ハイプロに隠れないことを気にしすぎて上へ寄せないように注意。

DN0010、DN0011では左右に3個ずつ配置しているが、左右どちらかのみの、非対称の配置としてもよい。

jpskenn, 2024-11-30:
移動案。
○1個分だけ左へ。
○のサイズを一回りくらい小さく。
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

jpskenn, 2024-11-30:
変更後
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

jpskenn, 2024-11-30:
変更後、バリエーション。
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

Closed 2024-11-30.

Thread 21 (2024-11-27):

製造時SMTAでBasicパーツにできるものは？

jpskenn, 2024-11-27:
- ExtendedからBasicへの変更（別の製品や、サイズ変更0402→0603など）
- 不要パーツの削除（電源LEDなくすか、Basicに変更）

基板のパーツ配置が厳しいとかあるので、あまりかんばってやりすぎない程度に。

jpskenn, 2024-12-01:
変更できそうなもの
- [ ] 電源降圧まわりのC1,C2
- [x] 電源LED
  →取り付けない

jpskenn, 2024-12-01:
1def906fd2fdaf38bacac3542d050d7da5a42a59

Closed 2024-12-01.

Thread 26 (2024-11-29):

KiCad ロードエラー

jpskenn, 2024-11-29:
[不要ファイル削除](https://github.com/jpskenn/SandyLP/issues/16)で消したものが、KiCadのライブラリ設定に残っているので、KiCadのライブラリ設定を修正する。

jpskenn, 2024-11-30:
d71de198f5a5b8b347e6fd13d99f196cafbc44fd

Closed 2024-11-30.

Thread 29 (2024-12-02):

ブラッシュアップ案の取り込み

jpskenn, 2024-12-02:
どこまで取り込めるかは不明だが、アイデアとして参照。

jpskenn, 2024-12-02:
- もうちょい幅を広げた一体型
  →あまり広げるとマウスとトラックパッドに当たる。
  →製造費が上がってしまう。
  →やめ。
- もしかして分割型
  →
  →やるなら別プロジェクトで。
- LEDの位置変更・LED窓の形状変更
- ケースの底は無くてよい
- ボトムプレートを左右に拡大してケースに接続
- DIPスイッチ・トグルスイッチ
- 基板の反り防止

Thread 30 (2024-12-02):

Mid→Topの3.5mmスペーサー廃止に伴う変更

jpskenn, 2024-12-02:
3.5mmスペーサーから、3mmスペーサー＋0.4mmワッシャーに変更。
この変更に関連する部分。

- [ ] ビルドガイド
- [ ] ネジ穴アイコン

先に組み付ける方にワッシャーを挟む。→Mid中央うら側

jpskenn, 2024-12-03:
ff5e7f210c59155a460c7598fff4204700e3bb7c

jpskenn, 2024-12-03:
基板のネジ穴アイコン変更がまだだったので、Reopen

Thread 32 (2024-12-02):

ボトムプレートを10×10に分割

jpskenn, 2024-12-02:
製造費を下げるため、10×10cm以内に分割できるか？

### 分割イメージ
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

### 利点
- コスト下げ

### 懸念・欠点
- でかいロゴを入れられない（ロゴが切れる）
- 重量低下による安定感等の低下
- 底面がひとつの平面でなくなる（左右でアンバランス、ガタつき）
- Base基板のネジ穴増加
- 強度低下（Base基板1枚で全体を支える。ねじれとか？）

jpskenn, 2024-12-02:
コスト低下は見込まれるが、他にメリットがなく、懸念されるデメリットの方が多いため、ボツ。

Closed 2024-12-02.

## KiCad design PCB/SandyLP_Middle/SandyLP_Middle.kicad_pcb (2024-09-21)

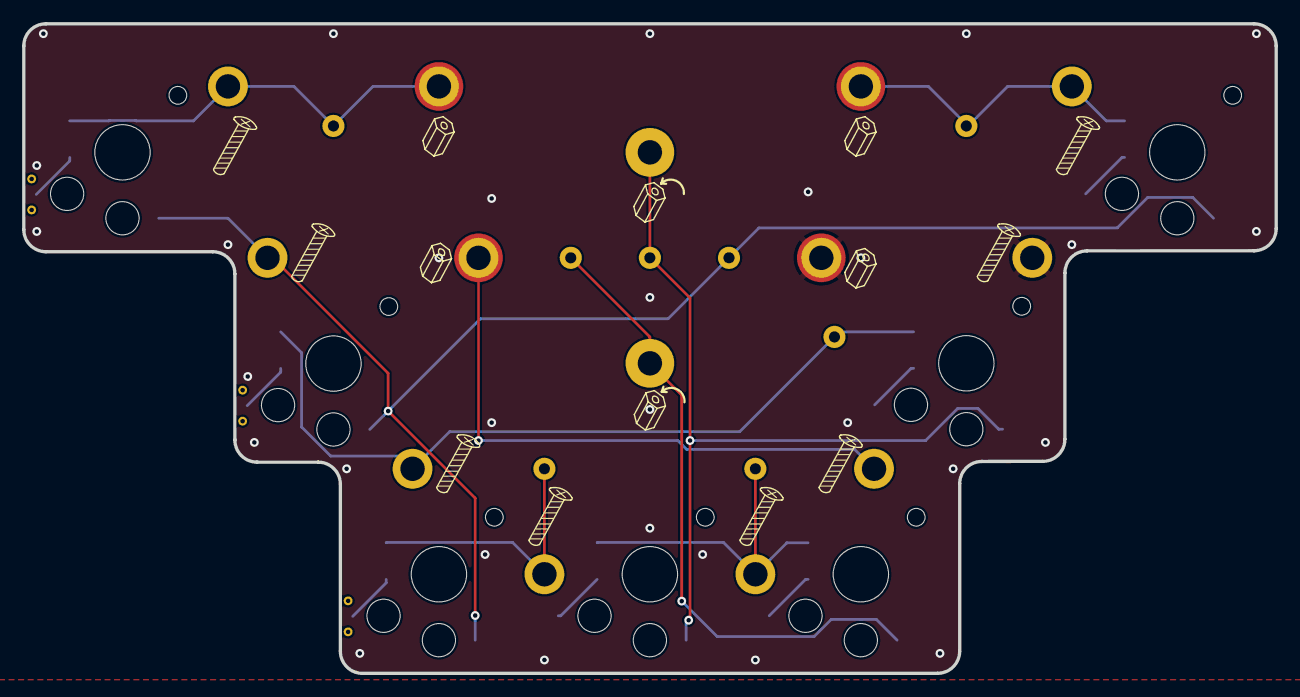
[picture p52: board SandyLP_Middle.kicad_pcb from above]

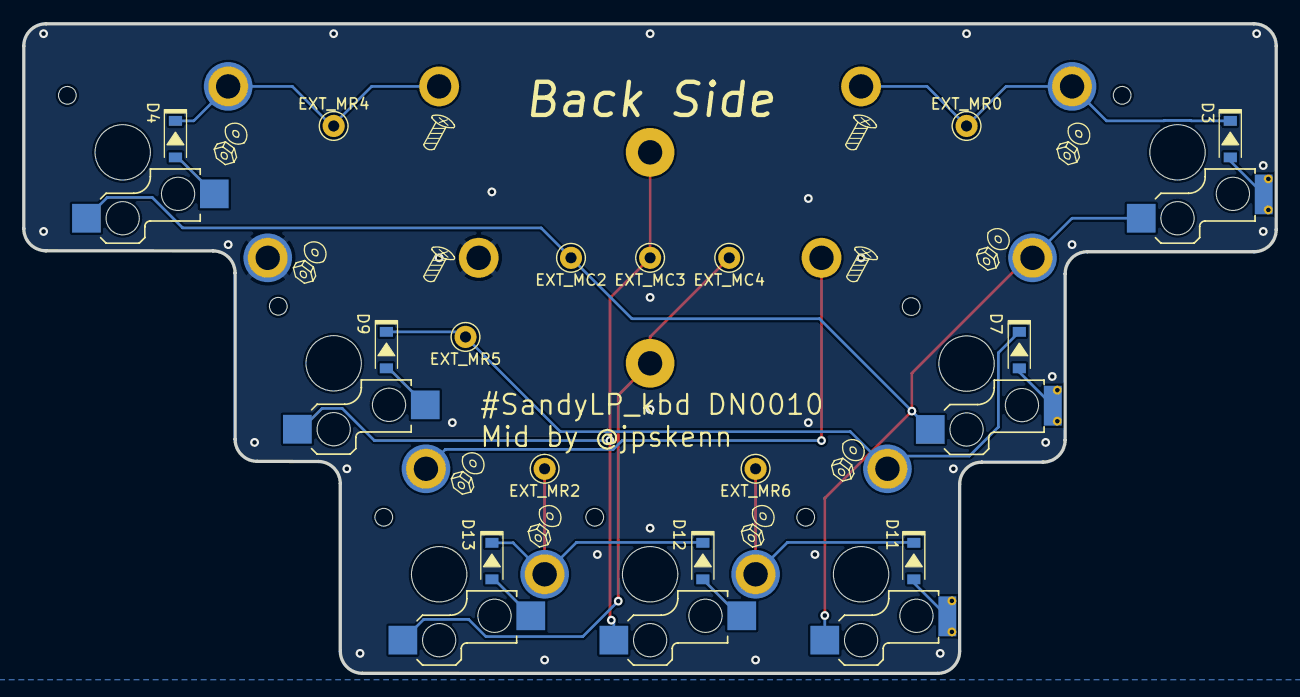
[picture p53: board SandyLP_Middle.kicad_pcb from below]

Board: 2 copper layers, 113.1 x 58.7 mm, 37 parts (21 on the bottom side), 17 nets.

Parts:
Cutout1: 60_Outline; SandyLP_outline_Mid
D3, D4, D7, D9, D11, D12, D13: D; D_SOD-123_Emphasized_Direction_Line
EXT_MC2, EXT_MC3, EXT_MC4: Conn_01x01; TestPoint_THTPad_D2.0mm_Drill1.0mm
EXT_MR0, EXT_MR2, EXT_MR4, EXT_MR5, EXT_MR6: Conn_01x01; TestPoint_THTPad_D2.0mm_Drill1.0mm
H1, H2, H3, H4, H5, H6, H7, H8: MountingHole; MountingHole_1.8-2.2mm_M2_Pad_minimal
H_top_1, H_top_3, H_top_4, H_top_5: MountingHole; MountingHole_1.8-2.2mm_M2_Pad_minimal
H_top_2, H_top_6: MountingHole; MountingHole_2.2mm_M2_Pad_minimal
SW_G1: SW_Push; Kailh_socket_ChocV2_small_#2pad
SW_H1: SW_Push; Kailh_socket_ChocV2
SW_R1, SW_R4CNT_L1: SW_Push; Kailh_socket_ChocV2_small_#2pad
SW_R4CNT_C1, SW_R4CNT_R1: SW_Push; Kailh_socket_ChocV2
SW_U1: SW_Push; Kailh_socket_ChocV2

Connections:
GND: H4.1, H_top_5.1
Mid_col2: EXT_MC2.1, H3.1, SW_G1.1, SW_R1.1, SW_R4CNT_L1.1, SW_U1.1
Mid_col3: EXT_MC3.1, H_top_2.1, SW_H1.1, SW_R4CNT_C1.1
Mid_col4: EXT_MC4.1, H_top_6.1, SW_R4CNT_R1.1
Mid_row0: D3.1 (K), EXT_MR0.1, H1.1, H_top_1.1
Mid_row1: H6.1, H_top_4.1
Mid_row2: D12.1 (K), D13.1 (K), EXT_MR2.1, H8.1
Mid_row4: D4.1 (K), EXT_MR4.1, H2.1, H_top_3.1
Mid_row5: D7.1 (K), D9.1 (K), EXT_MR5.1, H5.1
Mid_row6: D11.1 (K), EXT_MR6.1, H7.1
unnamed: D3.2 (A), SW_R1.2
unnamed: D4.2 (A), SW_U1.2
unnamed: D7.2 (A), SW_G1.2
unnamed: D9.2 (A), SW_H1.2
unnamed: D11.2 (A), SW_R4CNT_L1.2
unnamed: D12.2 (A), SW_R4CNT_C1.2
unnamed: D13.2 (A), SW_R4CNT_R1.2

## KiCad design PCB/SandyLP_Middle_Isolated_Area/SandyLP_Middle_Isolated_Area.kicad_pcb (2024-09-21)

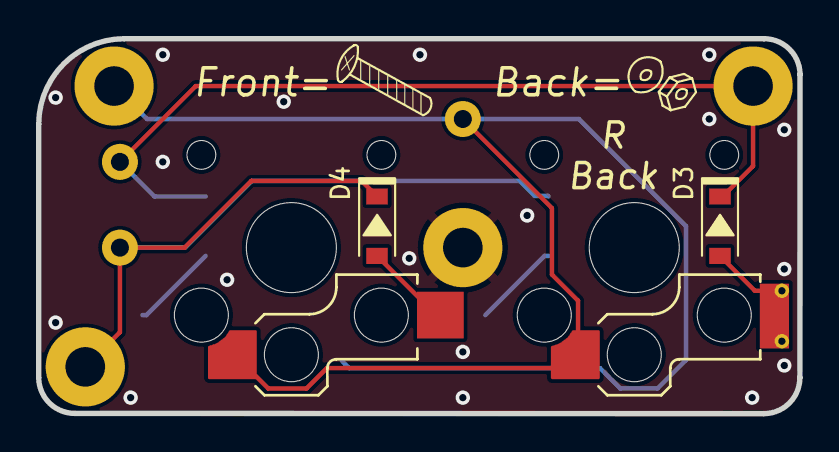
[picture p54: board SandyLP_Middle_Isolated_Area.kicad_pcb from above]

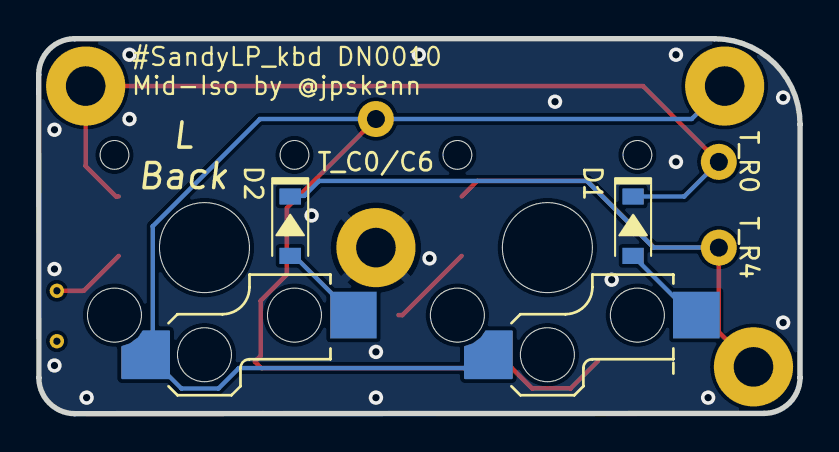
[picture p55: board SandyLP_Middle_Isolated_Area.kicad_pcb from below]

Board: 2 copper layers, 42.3 x 20.8 mm, 16 parts (11 on the bottom side), 7 nets.

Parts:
Cutout1: 60_Outline; SandyLP_outline_Mid_Isolated_Area_gentle_corner
D1, D2, D3, D4: D; D_SOD-123_Emphasized_Direction_Line
H1, H2, H3, H4: MountingHole; MountingHole_2.2mm_M2_Pad_minimal
SW_BS1: SW_Push; Kailh_socket_ChocV2_for_Reverse_no_hole
SW_P1: SW_Push; Kailh_socket_ChocV2_small_#2pad_for_Reverse_no_hole
SW_Q1: SW_Push; Kailh_socket_ChocV2_for_Reverse
SW_TAB1: SW_Push; Kailh_socket_ChocV2_for_Reverse
T_C0/C6: Conn_01x01; TestPoint_THTPad_D2.0mm_Drill1.0mm
T_R0, T_R4: Conn_01x01; TestPoint_THTPad_D2.0mm_Drill1.0mm

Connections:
Mid_col0/6: H1.1, SW_BS1.1, SW_P1.1, SW_Q1.1, SW_TAB1.1, T_C0/C6.1
Mid_row0: D1.1 (K), D3.1 (K), H3.1, T_R0.1
Mid_row4: D2.1 (K), D4.1 (K), H2.1, T_R4.1
unnamed: D1.2 (A), SW_TAB1.2
unnamed: D2.2 (A), SW_Q1.2
unnamed: D3.2 (A), SW_P1.2
unnamed: D4.2 (A), SW_BS1.2

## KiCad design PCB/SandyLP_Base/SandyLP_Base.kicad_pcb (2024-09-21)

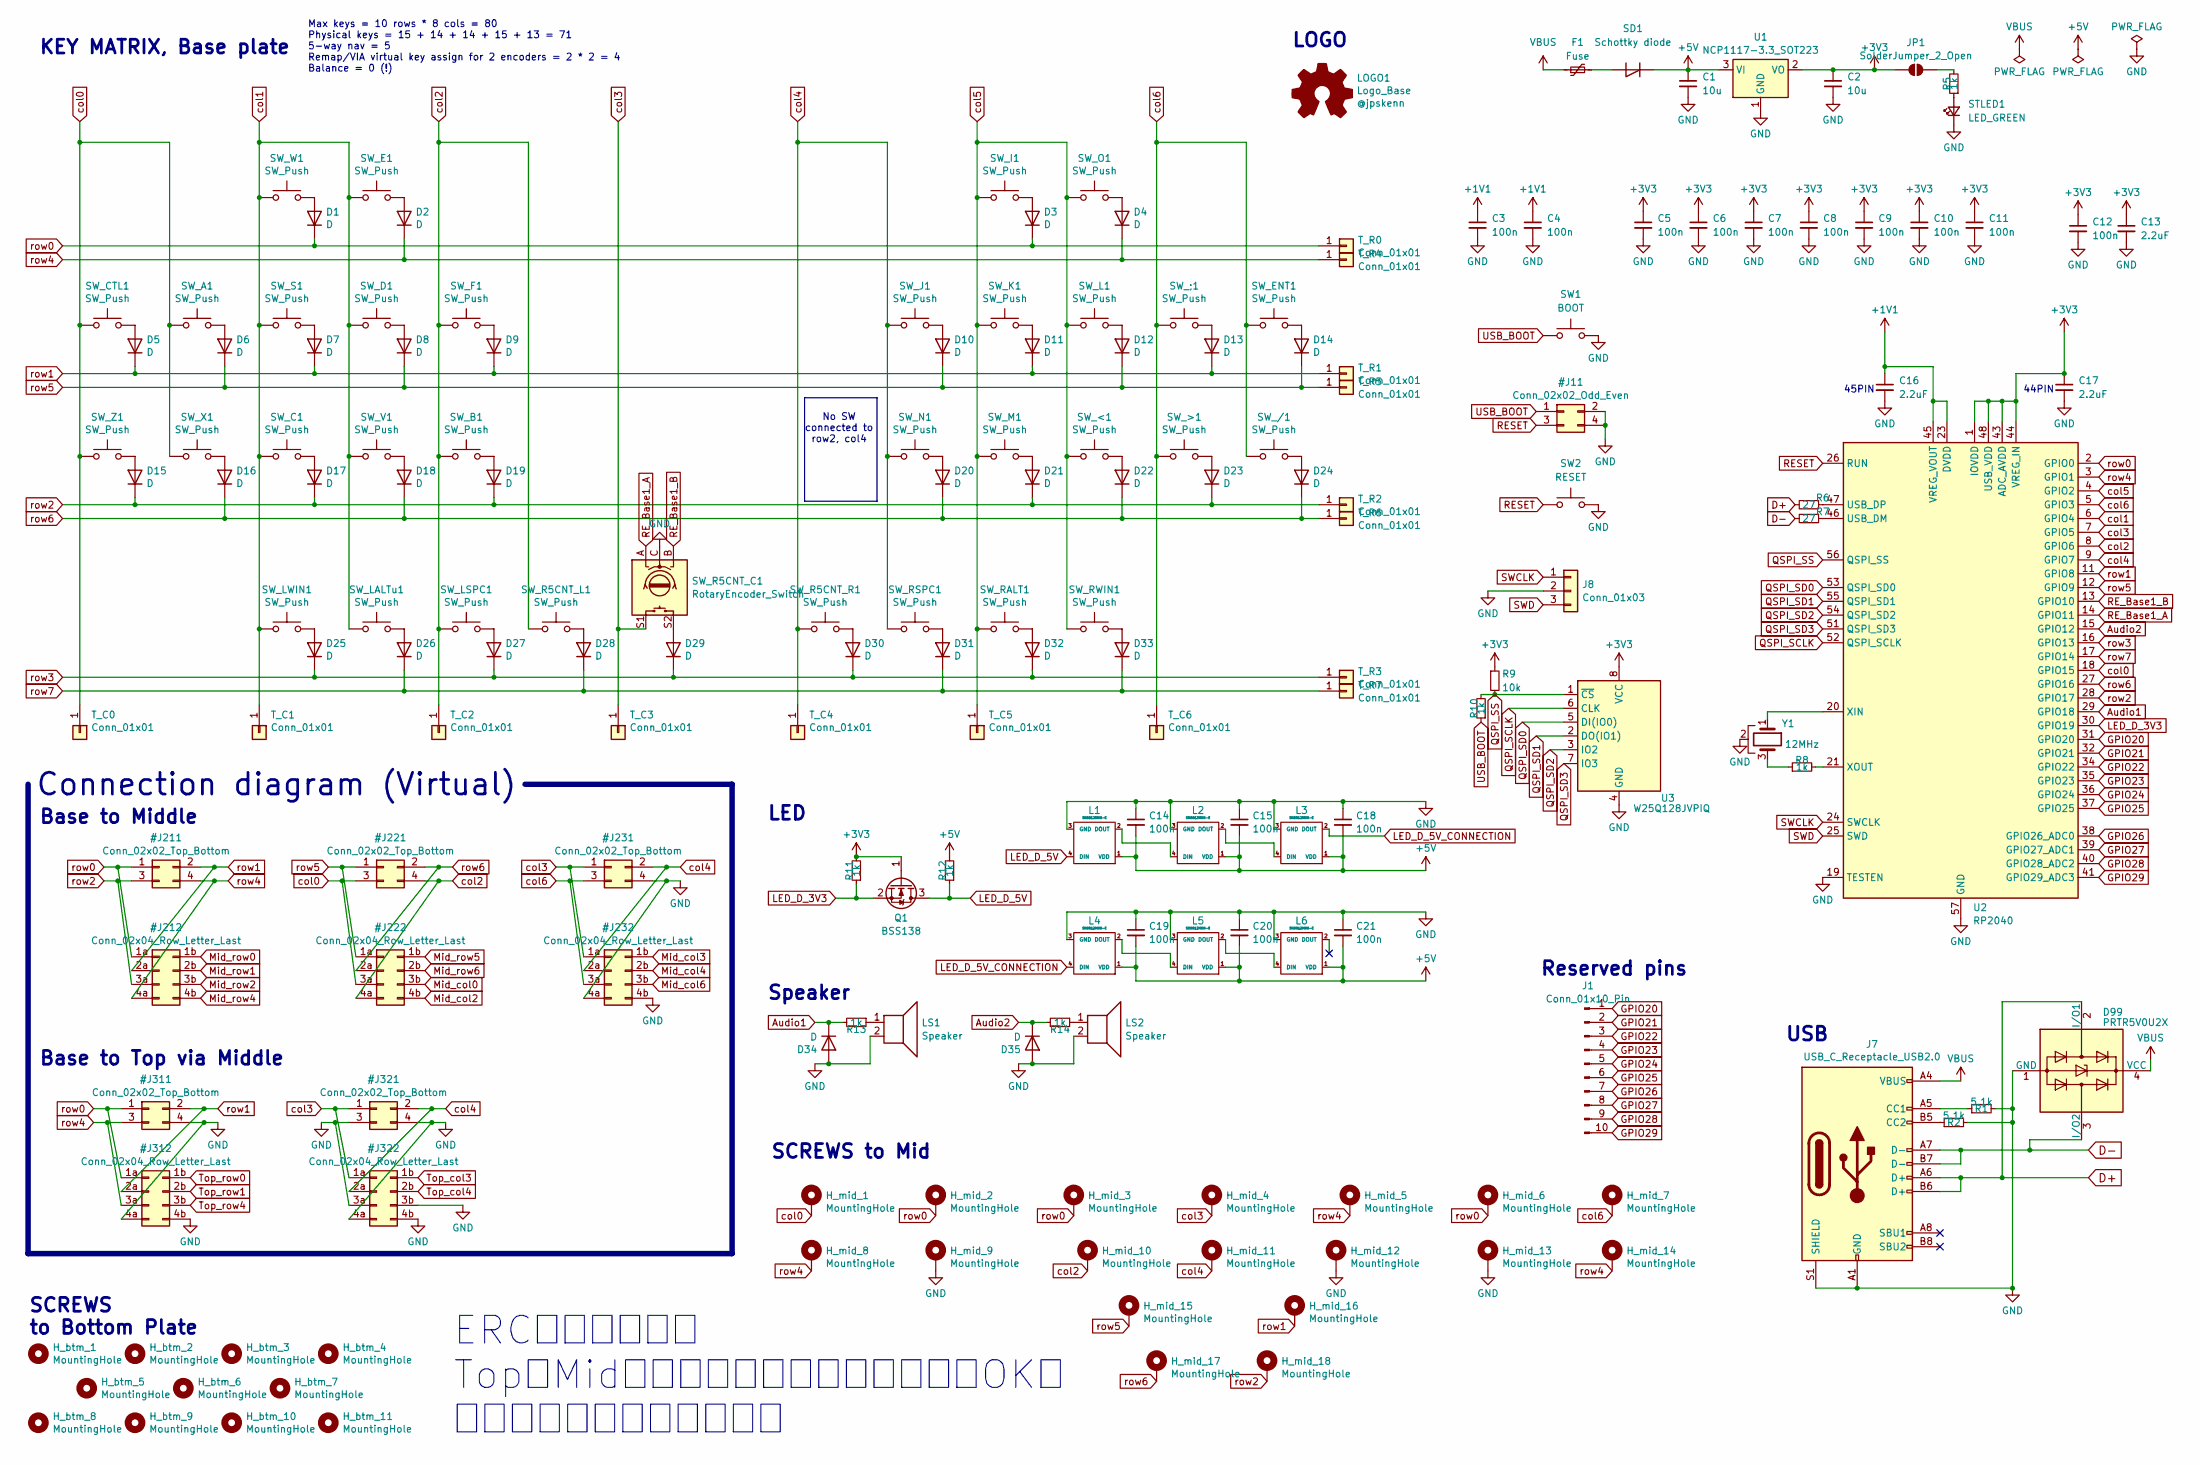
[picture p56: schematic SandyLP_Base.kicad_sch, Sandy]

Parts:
C1, C2: 10u; C_1206_3216Metric; LCSC C77090
C3, C4, C5, C6, C7, C8, C9, C10, C11, C12, C14, C15, C18, C19, C20, C21: 100n; C_0402_1005Metric; LCSC C1525
C13, C16, C17: 2.2uF; C_0402_1005Metric; LCSC C307418
D1, D2, D3, D4, D5, D6, D7, D8, D9, D10, D11, D12, D13, D14, D15, D16, D17, D18, D19, D20, D21, D22, D23, D24, D25, D26, D27, D28, D29, D30, D31, D32, D33, D34, D35: D; D_SOD-123_Emphasized_Direction_Line_Reference_on_bottom; LCSC C81598
D99: PRTR5V0U2X; SOT-143; LCSC C78442
F1: Fuse; Fuse_0603_1608Metric; LCSC C187605
H_btm_1, H_btm_2, H_btm_3, H_btm_4, H_btm_5, H_btm_6, H_btm_7, H_btm_8, H_btm_9, H_btm_10, H_btm_11: MountingHole; MountingHole_2.2mm_M2_No_Cu
H_mid_1, H_mid_2, H_mid_3, H_mid_4, H_mid_5, H_mid_6, H_mid_7, H_mid_8, H_mid_9, H_mid_10, H_mid_11, H_mid_12, H_mid_13, H_mid_14, H_mid_15, H_mid_16, H_mid_17, H_mid_18: MountingHole; MountingHole_1.8-2.2mm_M2_Pad_minimal
J1: Conn_01x10_Pin; PinHeader_1x10_P1.00mm_Vertical
J7: USB_C_Receptacle_USB2.0; USB_C_Receptacle_HRO_TYPE-C-31-M-12; LCSC C165948
J8: Conn_01x03; PinHeader_1x03_P2.54mm_Vertical_All_circle
JP1: SolderJumper_2_Open; SolderJumper-2_P1.3mm_Open_RoundedPad1.0x1.5mm
L1, L2, L3, L4, L5, L6: SK6812MINI-E; YS-SK6812MINI-E_middle_hole_with_small_pad
LOGO1: Logo_Base; SandyLP_logo_LP40_w60
LS1, LS2: Speaker; Buzzer_Murata_PKMCS0909E; LCSC-Reserve C910763
Q1: BSS138; SOT-23; LCSC C78284
R1, R2: 5.1k; R_0402_1005Metric; LCSC C25905
R5, R8, R10, R11, R12, R13, R14: 1k; R_0402_1005Metric; LCSC C11702
R6, R7: 27; R_0402_1005Metric; LCSC C25100
R9: 10k; R_0402_1005Metric; LCSC C25744
SD1: Schottky diode; D_SOD-123; LCSC C8598
STLED1: LED_GREEN; LED_0402_1005Metric; LCSC C130723
SW1: BOOT; SW_SPST_TL3342; LCSC-Reserve C2886897
SW2: RESET; SW_SPST_TL3342; LCSC-Reserve C2886897
SW_/1: SW_Push; Kailh_socket_ChocV2
SW_;1: SW_Push; Kailh_socket_ChocV2
SW_<1: SW_Push; Kailh_socket_ChocV2
SW_>1: SW_Push; Kailh_socket_ChocV2
SW_A1: SW_Push; Kailh_socket_ChocV2
SW_B1: SW_Push; Kailh_socket_ChocV2
SW_C1: SW_Push; Kailh_socket_ChocV2
SW_CTL1: SW_Push; Kailh_socket_ChocV2
SW_D1: SW_Push; Kailh_socket_ChocV2
SW_E1: SW_Push; Kailh_socket_ChocV2
SW_ENT1: SW_Push; Kailh_socket_ChocV2
SW_F1: SW_Push; Kailh_socket_ChocV2
SW_I1: SW_Push; Kailh_socket_ChocV2
SW_J1: SW_Push; Kailh_socket_ChocV2
SW_K1: SW_Push; Kailh_socket_ChocV2
SW_L1: SW_Push; Kailh_socket_ChocV2
SW_LALTu1: SW_Push; Kailh_socket_ChocV2
SW_LSPC1: SW_Push; Kailh_socket_ChocV2
SW_LWIN1: SW_Push; Kailh_socket_ChocV2
SW_M1: SW_Push; Kailh_socket_ChocV2
SW_N1: SW_Push; Kailh_socket_ChocV2
SW_O1: SW_Push; Kailh_socket_ChocV2
SW_R5CNT_C1: RotaryEncoder_Switch; ChocV2_AND_RotaryEncoder_Alps_EC11K-Switch_Vertical_H20mm_N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
SW_R5CNT_L1, SW_R5CNT_R1: SW_Push; Kailh_socket_ChocV2
SW_RALT1: SW_Push; Kailh_socket_ChocV2
SW_RSPC1: SW_Push; Kailh_socket_ChocV2
SW_RWIN1: SW_Push; Kailh_socket_ChocV2
SW_S1: SW_Push; Kailh_socket_ChocV2
SW_V1: SW_Push; Kailh_socket_ChocV2
SW_W1: SW_Push; Kailh_socket_ChocV2
SW_X1: SW_Push; Kailh_socket_ChocV2
SW_Z1: SW_Push; Kailh_socket_ChocV2
T_C0, T_C1, T_C2, T_C3, T_C4, T_C5, T_C6: Conn_01x01; TestPoint_THTPad_D2.0mm_Drill1.0mm
T_R0, T_R1, T_R2, T_R3, T_R4, T_R5, T_R6, T_R7: Conn_01x01; TestPoint_THTPad_D2.0mm_Drill1.0mm
U1: NCP1117-3.3_SOT223; SOT-223-3_TabPin2; LCSC C347222
U2: RP2040; RP2040-QFN-56; LCSC C2040
U3: W25Q128JVPIQ; WSON-8-1EP_6x5mm_P1.27mm_EP3.4x4.3mm; LCSC C190862
Y1: 12MHz; Resonator_SMD_Murata_CSTxExxV-3Pin_3.0x1.1mm; MFR.Part # CSTNE12M0G550000R0; LCSC C341520

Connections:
+1V1: C3.1, C4.1, C16.1, U2.23 (DVDD), U2.45 (VREG_VOUT), U2.50 (DVDD)
+3V3: C2.1, C5.1, C6.1, C7.1, C8.1, C9.1, C10.1, C11.1, C12.1, C13.1, C17.1, JP1.1 (A), Q1.1 (G), R9.1, R11.2, U1.2 (VO), U2.1 (IOVDD), U2.10 (IOVDD), U2.22 (IOVDD), U2.33 (IOVDD), U2.42 (IOVDD), U2.43 (ADC_AVDD), U2.44 (VREG_IN), U2.48 (USB_VDD), U2.49 (IOVDD), U3.8 (VCC)
+5V: C1.1, C14.2, C15.2, C18.2, C19.2, C20.2, C21.2, L1.1 (VDD), L2.1 (VDD), L3.1 (VDD), L4.1 (VDD), L5.1 (VDD), L6.1 (VDD), R12.2, SD1.1 (K), U1.3 (VI)
Audio1: D34.1 (K), R13.2, U2.29 (GPIO18)
Audio2: D35.1 (K), R14.2, U2.15 (GPIO12)
D+: D99.2 (I/O1), J7.A6 (D+), J7.B6 (D+), R6.2
D-: D99.3 (I/O2), J7.A7 (D-), J7.B7 (D-), R7.2
GPIO20: J1.1, U2.31 (GPIO20)
GPIO21: J1.2, U2.32 (GPIO21)
GPIO22: J1.3, U2.34 (GPIO22)
GPIO23: J1.4, U2.35 (GPIO23)
GPIO24: J1.5, U2.36 (GPIO24)
GPIO25: J1.6, U2.37 (GPIO25)
GPIO26: J1.7, U2.38 (GPIO26_ADC0)
GPIO27: J1.8, U2.39 (GPIO27_ADC1)
GPIO28: J1.9, U2.40 (GPIO28_ADC2)
GPIO29: J1.10, U2.41 (GPIO29_ADC3)
LED_D_3V3: Q1.2 (S), R11.1, U2.30 (GPIO19)
LED_D_5V: L1.4 (DIN), Q1.3 (D), R12.1
LED_D_5V_CONNECTION: L3.2 (DOUT), L4.4 (DIN)
unnamed: D1.2 (A), SW_W1.2
unnamed: D2.2 (A), SW_E1.2
unnamed: D3.2 (A), SW_I1.2
unnamed: D4.2 (A), SW_O1.2
unnamed: D5.2 (A), SW_CTL1.2
unnamed: D6.2 (A), SW_A1.2
unnamed: D7.2 (A), SW_S1.2
unnamed: D8.2 (A), SW_D1.2
unnamed: D9.2 (A), SW_F1.2
unnamed: D10.2 (A), SW_J1.2
unnamed: D11.2 (A), SW_K1.2
unnamed: D12.2 (A), SW_L1.2
unnamed: D13.2 (A), SW_;1.2
unnamed: D14.2 (A), SW_ENT1.2
unnamed: D15.2 (A), SW_Z1.2
unnamed: D16.2 (A), SW_X1.2
unnamed: D17.2 (A), SW_C1.2
unnamed: D18.2 (A), SW_V1.2
unnamed: D19.2 (A), SW_B1.2
unnamed: D20.2 (A), SW_N1.2
unnamed: D21.2 (A), SW_M1.2
unnamed: D22.2 (A), SW_<1.2
unnamed: D23.2 (A), SW_>1.2
unnamed: D24.2 (A), SW_/1.2
unnamed: D25.2 (A), SW_LWIN1.2
unnamed: D26.2 (A), SW_LALTu1.2
unnamed: D27.2 (A), SW_LSPC1.2
unnamed: D28.2 (A), SW_R5CNT_L1.2
unnamed: D29.2 (A), SW_R5CNT_C1.S2
unnamed: D30.2 (A), SW_R5CNT_R1.2
unnamed: D31.2 (A), SW_RSPC1.2
unnamed: D32.2 (A), SW_RALT1.2
unnamed: D33.2 (A), SW_RWIN1.2
unnamed: J7.A5 (CC1), R1.1
unnamed: J7.B5 (CC2), R2.1
unnamed: JP1.2 (B), R5.2
unnamed: L1.2 (DOUT), L2.4 (DIN)
unnamed: L2.2 (DOUT), L3.4 (DIN)
unnamed: L4.2 (DOUT), L5.4 (DIN)
unnamed: L5.2 (DOUT), L6.4 (DIN)
unnamed: LS1.1, R13.1
unnamed: LS2.1, R14.1
unnamed: R8.1, Y1.3
unnamed: F1.2, SD1.2 (A)
unnamed: R5.1, STLED1.2 (A)
unnamed: R7.1, U2.46 (USB_DM)
unnamed: R6.1, U2.47 (USB_DP)
unnamed: U2.20 (XIN), Y1.1
unnamed: R8.2, U2.21 (XOUT)
QSPI_SCLK: U2.52 (QSPI_SCLK), U3.6 (CLK)
QSPI_SD0: U2.53 (QSPI_SD0), U3.5 (DI(IO0))
QSPI_SD1: U2.55 (QSPI_SD1), U3.2 (DO(IO1))
QSPI_SD2: U2.54 (QSPI_SD2), U3.3 (IO2)
QSPI_SD3: U2.51 (QSPI_SD3), U3.7 (IO3)
QSPI_SS: R9.2, R10.2, U2.56 (QSPI_SS), U3.1 (~CS)
RE_Base1_A: SW_R5CNT_C1.A, U2.14 (GPIO11)
RE_Base1_B: SW_R5CNT_C1.B, U2.13 (GPIO10)
SWCLK: J8.1, U2.24 (SWCLK)
SWD: J8.3, U2.25 (SWD)
VBUS: D99.4 (VCC), F1.1, J7.A4 (VBUS), J7.A9 (VBUS), J7.B4 (VBUS), J7.B9 (VBUS)
col1: SW_C1.1, SW_D1.1, SW_E1.1, SW_LALTu1.1, SW_LWIN1.1, SW_S1.1, SW_V1.1, SW_W1.1, T_C1.1, U2.6 (GPIO4)
col5: SW_<1.1, SW_I1.1, SW_K1.1, SW_L1.1, SW_M1.1, SW_O1.1, SW_RALT1.1, SW_RWIN1.1, T_C5.1, U2.4 (GPIO2)
row3: D25.1 (K), D27.1 (K), D29.1 (K), D30.1 (K), D32.1 (K), T_R3.1, U2.16 (GPIO13)
row7: D26.1 (K), D28.1 (K), D31.1 (K), D33.1 (K), T_R7.1, U2.17 (GPIO14)

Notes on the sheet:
SCREWS to Mid
SCREWS to Bottom Plate
Speaker
No SW connected to row2, col4
Connection diagram (Virtual)
44PIN
USB
LOGO
45PIN
Reserved pins
Base to Top via Middle
Base to Middle
LED
ERCチェックで、 TopとMidのラベルが見つからないのはOK。 （別プロジェクトでやる）
KEY MATRIX, Base plate
Max keys = 10 rows * 8 cols = 80 Physical keys = 15 + 14 + 14 + 15 + 13 = 71 5-way nav = 5 Remap/VIA virtual key assign for 2 encoders = 2 * 2 = 4 Balance = 0 (!)

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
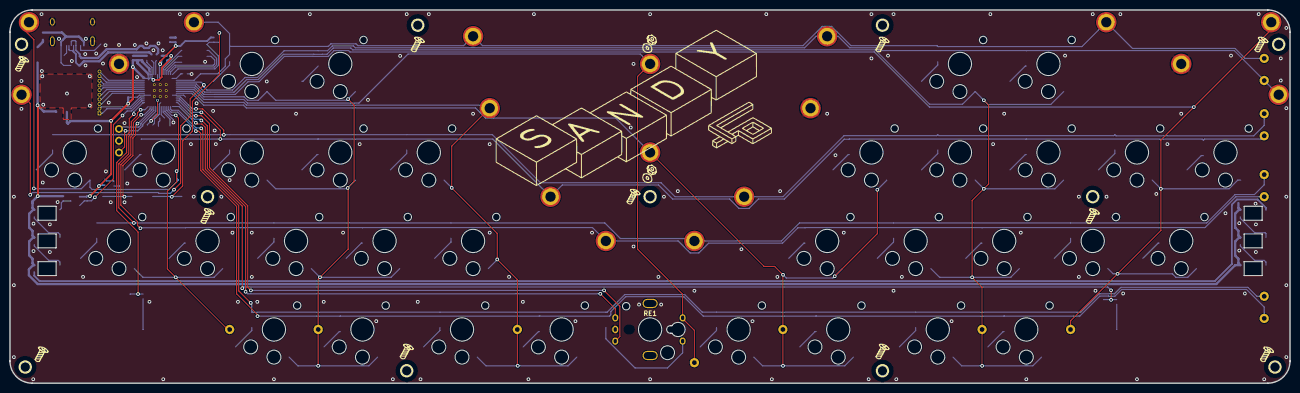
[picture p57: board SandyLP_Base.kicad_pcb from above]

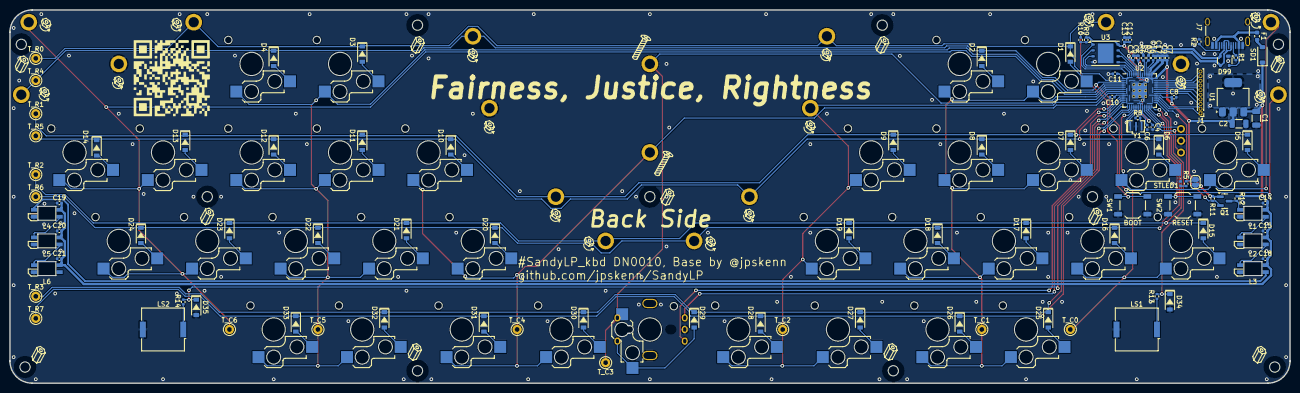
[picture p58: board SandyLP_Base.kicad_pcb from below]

Board: 2 copper layers, 275.5 x 80.3 mm, 169 parts (124 on the bottom side), 98 nets.

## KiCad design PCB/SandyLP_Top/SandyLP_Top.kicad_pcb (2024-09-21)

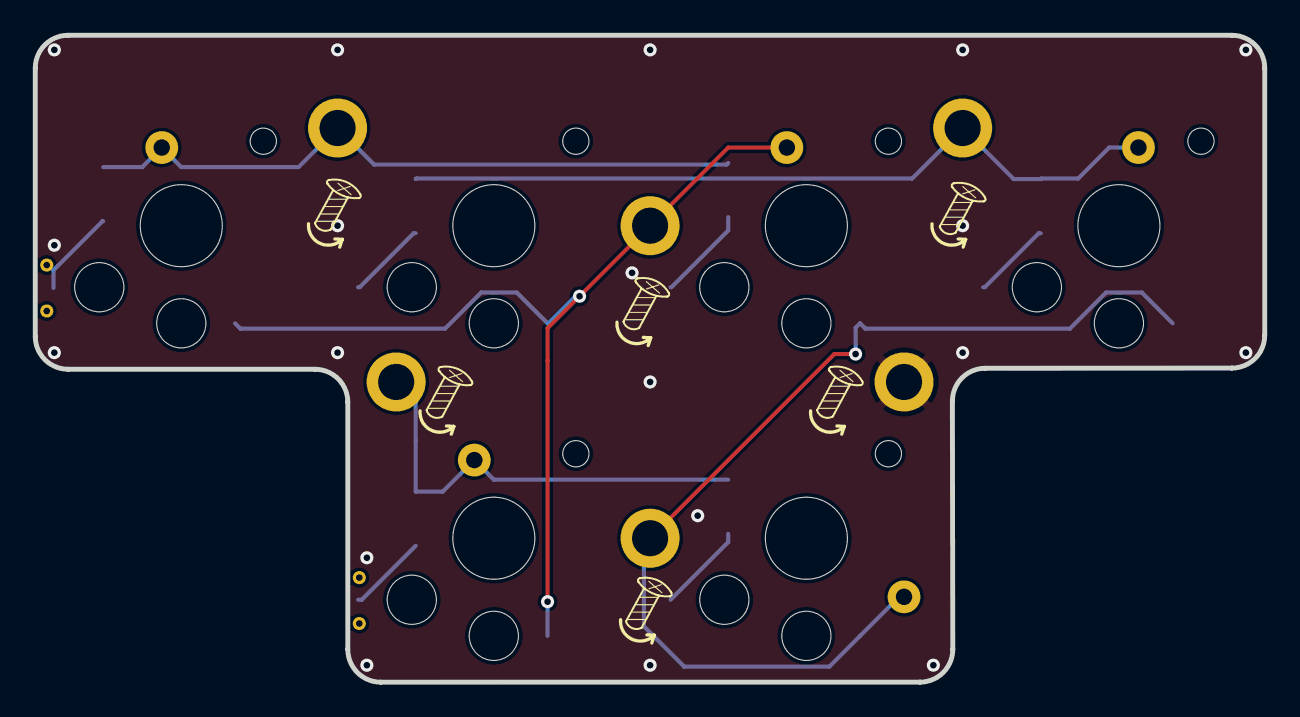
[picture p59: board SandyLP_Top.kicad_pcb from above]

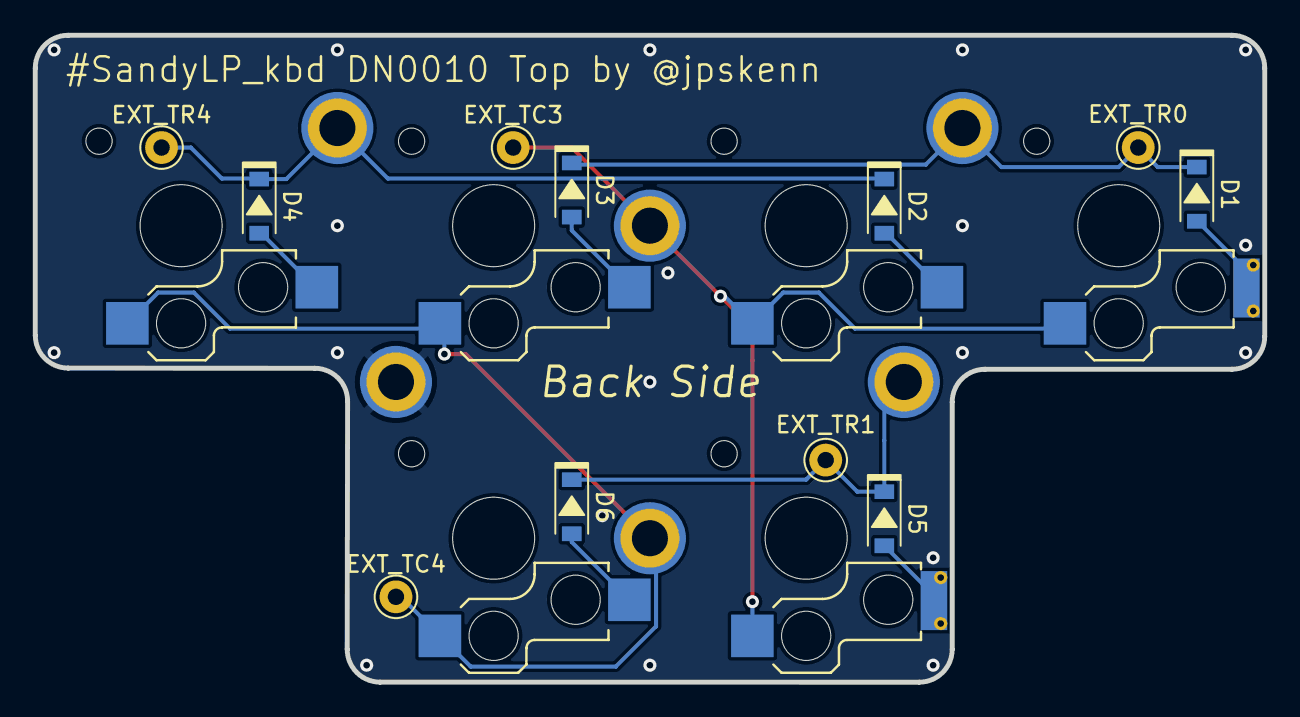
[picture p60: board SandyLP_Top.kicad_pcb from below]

Board: 2 copper layers, 74.9 x 39.4 mm, 23 parts (11 on the bottom side), 11 nets.

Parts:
D1, D2, D3, D4, D5, D6: D; D_SOD-123_Emphasized_Direction_Line
EXT_TC3, EXT_TC4: Conn_01x01; TestPoint_THTPad_D2.0mm_Drill1.0mm
EXT_TR0, EXT_TR1, EXT_TR4: Conn_01x01; TestPoint_THTPad_D2.0mm_Drill1.0mm
H1, H2, H3, H4, H5, H6: MountingHole; MountingHole_1.8-2.2mm_M2_Pad_minimal
SW_'1: SW_Push; Kailh_socket_ChocV2
SW_;1: SW_Push; Kailh_socket_ChocV2_small_#2pad
SW_T1: SW_Push; Kailh_socket_ChocV2
SW_Y1: SW_Push; Kailh_socket_ChocV2
SW_[1: SW_Push; Kailh_socket_ChocV2_small_#2pad
SW_]1: SW_Push; Kailh_socket_ChocV2

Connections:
unnamed: D1.2 (A), SW_[1.2
unnamed: D2.2 (A), SW_]1.2
unnamed: D3.2 (A), SW_Y1.2
unnamed: D4.2 (A), SW_T1.2
unnamed: D5.2 (A), SW_;1.2
unnamed: D6.2 (A), SW_'1.2
Top_col3: EXT_TC3.1, H2.1, SW_;1.1, SW_[1.1, SW_]1.1
Top_col4: EXT_TC4.1, H6.1, SW_'1.1, SW_T1.1, SW_Y1.1
Top_row0: D1.1 (K), D3.1 (K), EXT_TR0.1, H1.1
Top_row1: D5.1 (K), D6.1 (K), EXT_TR1.1, H4.1
Top_row4: D2.1 (K), D4.1 (K), EXT_TR4.1, H3.1

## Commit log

2024-09-13 migrate from Sandy repo.
    [LED_SK6812MINI-E.step, Sandy_Base.kicad_pcb, Sandy_Base.kicad_sch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]
2024-09-13 基板外形をLP版に変更。不要ファイル削除。
    [Sandy_Top.kicad_pcb]
2024-09-13 Topを仮配線。Midとの接続も一応確定
    [Sandy_Middle.kicad_sch, Sandy_Top.kicad_pcb, Sandy_Top.kicad_sch]
2024-09-13 不要ファイル削除
2024-09-13 ピン調整
    [Sandy_Middle.kicad_sch]
2024-09-13 プロジェクト名に沿って、名前を変更。
    [LED_SK6812MINI-E.step, SandyLP_Base.kicad_pcb, SandyLP_Base.kicad_sch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]
2024-09-13 スイッチの位置ずれ修正。ネジ位置調整。
    [SandyLP_Top.kicad_pcb, SandyLP_Top.kicad_sch]
2024-09-13 とりあえずフットプリントを配置。左右孤立部などは考え中。
    [SandyLP_Middle.kicad_pcb, SandyLP_Middle.kicad_sch]
2024-09-14 ネジ位置調整
    [SandyLP_Middle.kicad_pcb, SandyLP_Middle.kicad_sch]
2024-09-14 Mid孤立部分をリバーシブルで作成
    [SandyLP_Middle_Isolated_Area.kicad_pcb, SandyLP_Middle_Isolated_Area.kicad_sch]
2024-09-14 回路図編集：基板間接続、ネジ、フットプリント指定
    [SandyLP_Base.kicad_pcb, SandyLP_Base.kicad_sch]
2024-09-14 Base外形作成。ネジ配置。
    [SandyLP_Base.kicad_pcb, SandyLP_Base.kicad_sch]
2024-09-14 不要なものを整理。
    [SandyLP_Middle.kicad_pcb]
2024-09-14 ネジ位置変更
    [SandyLP_Middle_Isolated_Area.kicad_pcb]
2024-09-14 基板外形を調整。ネジ位置変更。ゾーンのクリアランス調整。
    [SandyLP_Middle_Isolated_Area.kicad_pcb, SandyLP_Middle_Isolated_Area.kicad_sch]
2024-09-14 サーマルスポーク幅調整
    [SandyLP_Base.kicad_pcb]
2024-09-14 WIP パーツ配置
    [SandyLP_Base.kicad_pcb, SandyLP_Base.kicad_sch]
2024-09-14 add "art board"
2024-09-14 ロゴ更新。パーツ配置調整中。
    [SandyLP_Base.kicad_pcb]
2024-09-14 USBコネクタ周りの配線に合わせて、Mid孤立部分のネジへのピン割り当てを変更。
    [SandyLP_Base.kicad_pcb, SandyLP_Base.kicad_sch, SandyLP_Middle_Isolated_Area.kicad_pcb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]
2024-09-15 配線完了。ビア打ちまだ。
    [SandyLP_Base.kicad_pcb, SandyLP_Base.kicad_sch]
2024-09-15 基板外形を調整
    [SandyLP_Middle.kicad_pcb]
2024-09-15 外形調整。スイッチ穴配置。
    [SandyLP_Plate_Top.kicad_pcb, SandyLP_Plate_Top.kicad_sch]
2024-09-15 スイッチ穴配置。
    [SandyLP_Plate_Middle.kicad_pcb, SandyLP_Plate_Middle.kicad_sch]
2024-09-15 ロゴ追加
    [SandyLP_Plate_Base.kicad_pcb]
2024-09-15 ロゴ修正
2024-09-15 ChocスイッチのFシルク削除
    [SandyLP_Base.kicad_pcb]
2024-09-15 後からねじ止めするアイコン（＝ドライバー）に変更
    [SandyLP_Top.kicad_pcb]
2024-09-15 外形のコーナーを緩く。LOGOの設定修正。
    [SandyLP_Base.kicad_pcb]
2024-09-15 外形のコーナーを緩く。
    [SandyLP_Middle_Isolated_Area.kicad_pcb]
2024-09-15 スイッチ穴をPTHに変更。
    [SandyLP_Plate_Middle_Isolated_area.kicad_pcb, SandyLP_Plate_Middle_Isolated_area.kicad_sch]
2024-09-16 LED窓の形状を丸に変更し、位置を調整。
    [SandyLP_Plate_Base.kicad_pcb]
2024-09-16 ビア打ち
    [SandyLP_Base.kicad_pcb]
2024-09-16 ネジ穴にアイコンを追加
    [SandyLP_Base.kicad_pcb]
2024-09-16 ネジ穴のアイコンを更新
    [SandyLP_Middle.kicad_pcb]
2024-09-16 基板厚を指定。STEPファイル出力設定。
    [SandyLP_Base.kicad_pcb, SandyLP_Middle.kicad_pcb, SandyLP_Middle_Isolated_Area.kicad_pcb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]
2024-09-16 ロータリーエンコーダの穴サイズを縦に拡大
    [SandyLP_Plate_Base.kicad_pcb, SandyLP_Plate_Base.kicad_sch]
2024-09-16 ロータリーエンコーダの配置方向を縦から横に変更。
    ロータリーエンコーダの端子がプレートに当たるのを回避するようにスイッチプレートの縦を広げると、Base用スイッチプレートの枠が細くなりすぎて強度が足りなくなるため、ロータリーエンコーダの配置方向を変更指定対応した。
    [SandyLP_Base.kicad_pcb, SandyLP_Plate_Base.kicad_pcb]
2024-09-16 不要シルク削除
    [SandyLP_Base.kicad_pcb]
2024-09-16 ボトムプレートとの接続アイコンを修正
    [SandyLP_Base.kicad_pcb]
2024-09-16 大きいサイズを書き出し
2024-09-16 ボトムプレート作成
    [LED_SK6812MINI-E.step, SandyLP_Plate_Bottom.kicad_pcb, SandyLP_Plate_Bottom.kicad_sch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]
2024-09-16 Top基板裏面のパーツ干渉を回避するため、穴を開けた。
    [SandyLP_Plate_Middle-B_Cu.gbl, SandyLP_Plate_Middle-B_Fab.gbr, SandyLP_Plate_Middle-B_Mask.gbs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]
2024-09-16 オプションが無料になったのでJLCのマーキングを削除。その他シルク位置調整。
    [SandyLP_Base.kicad_pcb, SandyLP_Middle.kicad_pcb, SandyLP_Middle_Isolated_Area.kicad_pcb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]
2024-09-16 Top基板裏面のパーツ干渉を回避するための穴が、前面から見えにくいように位置調整。
    [SandyLP_Plate_Middle.kicad_pcb]
2024-09-16 太めのバージョンを追加
2024-09-16 底面ロゴのサイズを大きく
    [SandyLP_Plate_Bottom.kicad_pcb, SandyLP_Plate_Bottom.kicad_sch]
2024-09-17 書き始め
2024-09-17 ロゴを大きく
    [SandyLP_Plate_Bottom.kicad_pcb]
2024-09-17 QRコードの位置調整
    [SandyLP_Plate_Bottom.kicad_pcb]
2024-09-17 製造用ファイル出力
    [SandyLP_Base-B_Cu.gbl, SandyLP_Base-B_Fab.gbr, SandyLP_Base-B_Mask.gbs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]
2024-09-18 パーツなど追記
2024-09-18 基板Mid中央くらいまで
2024-09-18 バリエーションを追加
2024-09-18 基板Mid左右あたりまで
2024-09-18 マトリクスの未使用部分のメモを追加
    [SandyLP_Base.kicad_sch]
2024-09-18 Base基板まで
2024-09-19 スイッチプレートはこれから
2024-09-19 ゴムシート貼り付け
2024-09-19 ロゴ更新
    [SandyLP_Plate_Bottom.kicad_pcb]
2024-09-19 基板Baseにスローガンを書いているので、こちらは削除。
    [SandyLP_Plate_Bottom.kicad_pcb]
2024-09-19 ロゴ調整
2024-09-20 だいたい完成まで
2024-09-20 カスタマイズガイドまで
2024-09-20 初期ファームウェアあたりまで
2024-09-20 VIA用jsonと、その元ネタのKLE。
2024-09-20 Mid左右プレートは判別可能だった
2024-09-20 内容を充実
2024-09-21 シルク追加。ロゴのフットプリント指定を修正。
    [SandyLP_Base.kicad_pcb, SandyLP_Base.kicad_sch]
2024-09-21 各種部品の個数追記など
2024-09-22 番号なくても問題ないので削除
2024-09-22 用語統一など
2024-09-23 強調表示
2024-09-24 説明追加。フォーマット
2024-09-26 章立て変更。説明追加。
2024-09-29 100*100mmサイズで製造する3分割プレートの中央部
    [SandyLP_Plate_Base_Center-B_Cu.gbl, SandyLP_Plate_Base_Center-B_Fab.gbr, SandyLP_Plate_Base_Center-B_Mask.gbs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]
2024-09-29 45度回転させる前のファイルは10x10cmに治らないので削除
2024-09-29 100*100mmサイズで製造する3分割プレートの左右部
    [SandyLP_Plate_Base_LR-B_Cu.gbl, SandyLP_Plate_Base_LR-B_Fab.gbr, SandyLP_Plate_Base_LR-B_Mask.gbs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]
2024-10-01 取り付け位置
2024-10-01 ネジの表記を変更
2024-10-01 写真必要な箇所など洗い出し
2024-10-01 組み合わせる手順を変更
2024-10-02 組み合わせる手順
2024-10-02 折り畳み廃止
2024-10-02 細かなところを追記
2024-10-02 フォーマット
2024-10-02 区切り線無くても問題なし
2024-10-02 目次再生成
2024-10-02 写真追加。数量調整。
2024-10-03 写真追加
2024-10-03 電源LED。フォーマット
2024-10-03 説明を簡潔に
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2024-10-04 画像リンクの修正など
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2024-10-06 画像リンク修正
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2024-10-16 QMKのkeyboard_nameと混同していたのを修正
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2024-10-29 Revert "ヒントの表記をGithubのアラート表記に変更"
    This reverts commit 52fab7aa1da7ca3f3f7fa421fb6c2d8caec13257.
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2024-11-12 名称間違いを修正
2024-12-02 基板の名前間違いを修正
